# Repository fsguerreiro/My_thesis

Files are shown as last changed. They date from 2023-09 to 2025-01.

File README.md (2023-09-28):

# My PhD thesis: Building Integration of a Solar Air Heating System

### Abstract:

In order to achieve the global carbon emission target, the high fraction of locally
available renewable energy sources will become necessary to meet energy demand. Solar
energy is one of the most important renewable sources locally available for use in space
heating, cooling, hot water supply and power production. Building integrated solar thermal systems (BISTS) can be a potential solution towards the enhanced energy efficiency
and reduced operational cost in built environment. The current research aimed at developing an active solar air heating collector for building integration. This system consisted of
several asymmetric compound parabolic concentrating collectors with inverted transpired
absorber stacked on the top of each other capable of receiving direct solar insolation for 8
hours/day during the summer season. An optical analysis was carried out with the assistance of a 3D ray tracing technique in order to investigate the optical performance through
a parametric analysis, and thus to decide the design to be used as a prototype. It has dimensions of 0.42 m x 0.40 m x 1.25 m and concentration ration 2.28, able to absorb up
to 67% of direct solar radiation in the period of operation. Subsequently, the prototype
was experimentally tested by using five different air flow rates (22 – 60 kg/h) in open loop
configuration. Experimental results show that, on clear days and in periods of high solar
insolation (greater than 800 W/m²), the airflow temperature rise varied between 12 ºC
(at the highest airflow rate) and 27 ºC (at the smallest rate), characterising thus thermal
efficiencies between 52 – 62%. After experimental characterisation, a thermal modelling
based on energy balance was undertaken with the objective of simulating the collector’s
thermal performance for further control of multiple units connected altogether. Validation of this model indicates that it predicts data of air temperature delivered and energy
collected with uncertainties of ± 2 ºC and ± 50 W/m² of absorber area, respectively. The
thermal modelling was also used to predict the thermal performance of three collectors
connected in series and in parallel. The connection in series was able to deliver higher
outlet airflow temperatures (higher than 70 ºC on a clear day), whereas the connection in
parallel can collect more useful heat but delivering the same airflow temperature as if it
is leaving the first collector in series. Lastly, this model was used for simulating barley
drying. Three scenarios were employed to fulfill energy requirements: using only a gas
burner to heat the airflow to 60 °C, combining a solar heating system with a gas burner
to achieve the same temperature, and solely relying on the solar heating system without
an air temperature limit. For a specific airflow level, the gas burner system consumed the
most gas and had a solar fraction of 0, indicating full reliance on gas for heating. Conversely, the standalone Solar Air Heating System (SAHS) yielded less dried mass, but
both configurations achieved a solar fraction of 1, signifying exclusive reliance on solar
energy. Results demonstrate that incorporating solar air heating systems can significantly
reduce the need for natural gas heating. Specifically, the gas burner + SAHS in parallel
exhibited the lowest gas consumption and the highest solar fraction among all the gas
burner-based systems.

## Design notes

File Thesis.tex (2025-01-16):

\documentclass[12pt,a4paper,oneside,openright,fleqn]{report}

%----------------------------------- Loading packages==============================
\usepackage[a4paper,left=40mm,right=20mm,top=25mm,bottom=25mm,headheight=15pt,headsep=15pt,footskip=10mm,columnsep=1cm]{geometry}
\usepackage[backend=bibtex,style=authoryear,citestyle=authoryear,maxbibnames=8,maxcitenames=2,natbib=true,dashed=false,firstinits=true]{biblatex} %
\usepackage{latexsym,amssymb,amsmath,pifont} 				% Package of symbols
\usepackage[notintoc]{nomencl}										   % Insertion of List of Symbols
\usepackage{subcaption}                   								   % Captions in subfigures        
\usepackage{eurosym,wasysym}                                          % For the Euro symbol and other symbols
\usepackage[hidelinks,pdfencoding=auto]{hyperref}			 % Creation of hyperlink for citation
\usepackage{indentfirst} 		   		          							 % Indent first paragraph of a chapter
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
%\usepackage{rotating} 				              							% Rotation of figures
%\usepackage{fontenc}
%\usepackage{color} 						          						 % Edition of color in figures, pages, etc.
%\usepackage{yfonts}
%\usepackage{adjustbox}                                                   % Box an item (figure, text, etc.)
%\usepackage[bf]{caption} 												   % Edition of captions
%\usepackage{tablefootnote}												% Insertion of footnote in tables
%\usepackage{epstopdf}													  % Convert EPS to PDF file		
%\usepackage{url}
%\usepackage{fncychap} 
%\usepackage{lmodern} 
%\usepackage{bm}
%\usepackage{shorttoc} 
%\usepackage{lastpage} 
%\usepackage{changepage}
%\usepackage[normalem]{ulem} 

% ------------------------------------- Page settings =======================
\parindent 1cm          
\doublespacing	   	   
\captionsetup[table]{skip=0pt}
\setlength{\emergencystretch}{8pt}

% ---------------------------------- List settings =========================
\setlist{align=left,leftmargin=*,noitemsep,nosep,topsep=6pt}
\renewcommand{\labelitemi}{$\checked$}
\newcounter{descriptcount}
\renewcommand*\thedescriptcount{Step \arabic{descriptcount}:}

%------------------------------ Nomenclature settings =====================
\makenomenclature
\renewcommand{\nomname}{List of Symbols}
\renewcommand\nomgroup[1]{%
	\vspace{0.6cm}
	\item[\bfseries
	\ifstrequal{#1}{N}{\Large \hspace*{1.5cm} Latin}{%
		\ifstrequal{#1}{P}{\Large \hspace*{1.5cm} Greek}{%
			\ifstrequal{#1}{S}{\Large \hspace*{1.5cm} Subscripts}{%
				\ifstrequal{#1}{A}{\Large \hspace*{1.5cm} Acronyms}}}}]}
\setlength{\nomitemsep}{-8pt}
%\renewcommand*\nompreamble{\begin{multicols}{1}}
%\renewcommand*\nompostamble{\end{multicols}}
%\setlength{\columnsep}{0.8cm}

%-------------------------------------- List of references settings ====================
\addbibresource{References.bib}
\renewbibmacro{in:}{}
\DeclareNameAlias{sortname}{last-first}

%-----------------------------------Title and subtitle settings ======================
\setcounter{tocdepth}{3}
\setcounter{secnumdepth}{3}
\titleformat{\chapter}[display]{\normalfont\Huge\filcenter \bfseries}
{\vspace{-1.5cm} \titlerule[4pt] \vspace{3pt} \titlerule \vspace{1pc}%
	\Huge\MakeUppercase{\chaptertitlename} \thechapter}
{1pc}{\titlerule[2pt] \vspace{1pc} \Huge \MakeUppercase}
\titlespacing{\section}{0pc}{1pc}{1pc}
\titlespacing{\subsection}{0pc}{1pc}{0.75pc}
\titlespacing{\subsubsection}{0pc}{0.75pc}{0.5pc}

%------------------------------------------Tikz settings ==============================
\usetikzlibrary{shapes.arrows,shapes.geometric,positioning,arrows.meta,shapes,backgrounds,angles, quotes, decorations.pathreplacing,datavisualization}
\let\svtikzpicture\tikzpicture
\def\tikzpicture{\noindent\svtikzpicture}
\tikzset{
	ultra thin/.style= {line width=0.1pt}, very thin/.style=  {line width=0.2pt},
	thin/.style= {line width=0.4pt},% thin is the default
	semithick/.style=  {line width=0.6pt}, thick/.style=      {line width=0.8pt},
	very thick/.style= {line width=1.2pt}, ultra thick/.style={line width=1.6pt}
}
\tikzstyle{startstop} = [draw, rounded rectangle, minimum width=1.75cm, minimum height=1cm,text centered, draw=black,very thick]
\tikzstyle{input} = [trapezium, trapezium left angle=70, trapezium right angle=110, text width=7cm, minimum height=1cm, text centered, draw=black,very thick, node distance = 5.25cm]
\tikzstyle{decision} = [diamond, text width = 2.5cm, draw=black,very thick, text centered, node distance = 3.5cm, inner sep = 0pt]
\tikzstyle{block} = [rectangle, draw=black,very thick, text width = 2cm, text centered, text height = 0.5cm]
\tikzstyle{line} = [draw=black,very thick, -latex]
\tikzstyle{arrow} = [very thick,->,>=stealth]

\tdplotsetmaincoords{60}{110}
\pgfmathsetmacro{\rvec}{1.25}
\pgfmathsetmacro{\thetavec}{40}
\pgfmathsetmacro{\phivec}{40}

%------------------------------------------------ Initiating text ==========================

\begin{document}
	\raggedbottom
	\sloppy
	\setlength{\belowdisplayskip}{10pt}      \setlength{\abovedisplayskip}{-4pt}
	\pagenumbering{gobble}
	\input{Cover}
	
	\newpage
	\thispagestyle{empty}
	\printnomenclature[1.5cm]
	\newpage
	
	%\setcounter{page}{1}       \pagenumbering{roman}
	\pagestyle{fancy}		\lhead{}		\rhead{\nouppercase{\rightmark}}
	
	\clearpage     						\renewcommand*\contentsname{Table of contents}
	\tableofcontents				 \addtocontents{toc}{~\hfill\textbf{Page}\par}
	
	\clearpage     \addcontentsline{toc}{chapter}{List of Figures} 	  \listoffigures
	
	\clearpage     \addcontentsline{toc}{chapter}{List of Tables}      \listoftables
	
	\newpage
	\rhead{\nouppercase{\rightmark}}      \lhead{Chapter \thechapter}
	\setcounter{page}{1}       \pagenumbering{arabic}
	\input{Introduction}
	\input{Literature}
	\input{Optical}
	\input{Experimental}
	\input{Thermal}

	\input{Conclusions}
	\newpage
	\lhead{}
	\addcontentsline{toc}{chapter}{References}
	\printbibliography[title={References}]
	%\newpage
	
\end{document}

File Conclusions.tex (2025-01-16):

\chapter{Conclusions}
\label{Cap:Con}
%

%The conclusions from this PhD work are listed as follows:
%
%\begin{itemize}
%	\item Development of a 3D ray tracing for optical analysis of direct radiation to assist the selection of a collector design: an optical analysis has been undertaken to evaluate its optical efficiency considering factors as: glazing transmittance, truncation level, length and tertiary section height. The results show that there is a maximum value of optical efficiency for a particular parabolic reflector shape and a maximum value of glazing transmittance at different inclinations. The proposed air heater concentrator is able to absorb in average 67\% of direct solar radiation during most part of the day in the period evaluated;
%	
%	\item Performance of experimental work to characterise the specific type of collector:
%	the experiments were carried out in open loop configuration, where the air was blown by a 12-W fan with a voltage adaptor to vary the airflow rate. Experimental results were analysed for different airflow rates ranging between 0.04 and 0.115 kg/m$^2$.s. Results show that the maximum outlet air temperatures at solar noon (13:00 to 14:00) varied from 40 $^{\rm{o}}$C at the highest airflow to 52 $^{\rm{o}}$C at the lowest and the thermal efficiency varied from 52\% to 62\%. 
%	
%	\item Thermal modelling of the solar air heating concentrator and validation against experimental results: it was shown that, in general, the heat transfer model underestimates 65\% of the data and 95\% of the residues generated are between $\pm$2 $^{\rm{o}}$C and $\pm$50 W/m$^2$. In overall, the mean absolute error in terms of temperature was found to be 2\% and in terms of useful energy was 8\%. The model was also used to simulate results at nearly steady state condition. The thermal efficiency curve was plotted and compare it to the experimental one. The parameters of the Hottel-Whillier-Bliss equation were calculated by the thermal model with relative difference of 2\% and 10\%, respectively, in relation to the parameters of the experimental data.
%	
%	\item Thermal simulation of a system consisted of more than one collector connected together: The thermal modelling was also used to predict the thermal performance of three connected collectors in series and in parallel. The connection in series is able to deliver higher outlet airflow temperatures whereas the connection in parallel can collect more useful heat but delivering the same airflow temperature as if it is leaving the first collector in series.
%	
%	
%	\item Use of this thermal model for simulating barley drying: Three scenarios were considered to meet the energy demand: simulating only a gas burner to heat the airflow up to 60 $^{\rm{o}}$C; simulating the solar heating system and a gas burner to heat the airflow up to 60 $^{\rm{o}}$C, and; simulating only the solar heating system to heat the airflow with no air temperature limit. From an specific airflow level used in the simulations, the gas burner system has the highest gas volume consumption and a solar fraction of 0, meaning it relies completely on gas for heating. On the other hand, the SAHS standalone system produces less dried mass, but both connections have a solar fraction of 1, indicating that they rely solely on solar energy.
%	
%	
%\end{itemize}

%\begin{itemize}
%	\item Development of a 3D ray tracing method for optical analysis of direct radiation to assist in the selection of a collector design: An optical analysis was conducted to evaluate its optical efficiency, considering factors such as glazing transmittance, truncation level, length, and tertiary section height. The results indicate a maximum optical efficiency for a specific parabolic reflector shape and a peak glazing transmittance at different inclinations. The proposed air heater concentrator demonstrated the ability to absorb an average of 67\% of direct solar radiation during the evaluated period of the day.
%	
%	\item Performance of experimental work to characterise the specific type of collector: Experiments were carried out in an open-loop configuration, where air was blown using a 12-W fan with a voltage adaptor to vary the airflow rate. Experimental results were analysed for different airflow rates ranging from 0.04 to 0.115 kg/m$^2\cdot$s. The findings reveal that the maximum outlet air temperatures at solar noon (13:00 to 14:00) varied from 40\,$^{\circ}$C at the highest airflow to 52\,$^{\circ}$C at the lowest, with thermal efficiencies ranging between 52\% and 62\%.
%	
%	\item Thermal modelling of the solar air heating concentrator and validation against experimental results: The heat transfer model was found to underestimate 65\% of the data, with 95\% of the residuals falling within \(\pm2\,^{\circ}\text{C}\) and \(\pm50\,\text{W/m}^2\). Overall, the mean absolute error in temperature was 2\%, and in useful energy, it was 8\%. The model was also used to simulate results under nearly steady-state conditions. The thermal efficiency curve was plotted and compared with experimental data. The parameters of the Hottel-Whillier-Bliss equation were calculated by the thermal model, showing relative differences of 2\% and 10\%, respectively, compared to the experimental parameters.
%	
%	\item Thermal simulation of a system comprising multiple collectors connected together: The thermal model was employed to predict the thermal performance of three collectors connected in series and in parallel. The series connection was found to deliver higher outlet airflow temperatures, while the parallel connection captured more useful heat but delivered airflow temperatures equivalent to those from the first collector in the series.
%	
%	\item Application of the thermal model for simulating barley drying: Three scenarios were analysed to meet the energy demand: (1) simulating only a gas burner to heat airflow to 60\,$^{\circ}$C; (2) simulating the solar heating system combined with a gas burner to achieve the same temperature; and (3) simulating the solar heating system alone, without a temperature limit. At a specific airflow level, the gas burner system exhibited the highest gas consumption and a solar fraction of 0, relying entirely on gas for heating. Conversely, the standalone solar air heating system produced less dried mass, but both configurations had a solar fraction of 1, indicating complete reliance on solar energy.

% \end{itemize}

%This chapter has consolidated the findings and highlighted key milestones achieved during the study of the proposed solar air heater concentrator and its applications.
%
%The design of an air heater concentrator with a horizontally downward-facing absorber proved effective in concentrating solar thermal energy and minimising heat losses. Through 3D ray-tracing optical analysis, the study identified an optimal parabolic reflector shape and glazing transmittance for different inclinations. A tertiary section was found to enhance uniformity in energy distribution across the absorber, although it introduced higher optical losses. Further exploration of the tertiary section's impact through thermal modelling and outdoor experiments remains necessary. The developed concentrator demonstrated an average absorption of 67\% of direct solar radiation during the evaluation period, showcasing its potential efficiency.
%
%The fabrication of a solar air heating prototype was successfully detailed, with materials selected based on their suitability for solar energy applications. The carbon fibre weave with 85\% absorptivity was chosen as the absorber, while the \textit{Mirosun} reflector sheet with 95\% reflectivity and tempered clear glass with 90\% transmittance served as the reflector and glazing, respectively. The experimental setup included a 12-W fan for airflow adjustment, enabling tests at varying flow rates. Results indicated that outlet air temperatures ranged from 40$^{\circ}$C  at the highest airflow to 52$^{\circ}$C  at the lowest, while thermal efficiency varied between 52\% and 62\% under peak solar noon conditions.
%
%Experimental findings were complemented by thermal modelling and simulation. Validation of the thermal model against experimental data showed a mean absolute error of 2\% for temperature and 8\% for useful energy. The parameters of the Hottel-Whillier-Bliss equation derived from the experimental data ( and ) closely matched those obtained from the model, with relative differences of 2\% and 10\%, respectively. The model’s robustness enabled simulations to predict performance under steady-state conditions and explore configurations of connected collectors. Collectors in series provided higher outlet air temperatures, whereas parallel connections increased useful heat collection without raising airflow temperatures beyond the initial collector’s output.
%
%The system’s potential for practical applications, such as barley drying, was investigated using the thermal model. Three scenarios highlighted the role of solar air heating systems (SAHS) in reducing dependence on natural gas. The standalone SAHS demonstrated a solar fraction of 1, while the gas burner + SAHS parallel configuration achieved the lowest gas consumption and highest solar fraction among hybrid systems. These findings underscore the potential for significant reductions in natural gas reliance, contingent on sunlight availability, natural gas costs, and system accessibility.
%
%In summary, this study has successfully designed, fabricated, and evaluated a solar air heating system. Key milestones include identifying optimal design parameters, validating a thermal model against experimental data, and demonstrating the system’s practical applications. The results reinforce the viability of solar air heating as a sustainable and efficient alternative to conventional energy sources, with opportunities for further optimisation and scalability.

This chapter concludes the research undertaken for this PhD by summarising its key findings, revisiting the objectives and contributions, and outlining potential directions for future work. The study focused on the development, testing, and modelling of a solar air-heating concentrator, aiming to enhance its design and performance for building-integrated applications. In the final phase, the system’s modelling was applied to address the energy demands of a barley drying operation. 

The chapter is organized as follows:

\begin{itemize}
	\item A detailed summary of the primary conclusions of this research and key findings, addressing the specific objectives described in Chapter \ref{Cap:Int};
	\item Suggestions for future research to build upon the outcomes.
\end{itemize}

\section{Main conclusions and key findings}

The main conclusions drawn from this PhD research are summarised as follows:

\begin{itemize}
	\item \textbf{Development of a 3D ray-tracing model for optical analysis of direct radiation to assist in the selection of a collector design}: \\
	A comprehensive optical analysis was conducted to evaluate the optical efficiency of the proposed collector design, considering factors such as glazing transmittance, truncation level, length, and tertiary section height. The findings reveal that there was an optimal parabolic reflector shape that maximises optical efficiency, as well as a peak glazing transmittance value for specific inclinations. The analysis was also able to calculate the effect of the tertiary section height on the energy distribution over the absorber plate. All of those design parameters were evaluated to select the concentrator's shape and size for further fabrication: concentration ratio of 2.28 and capability to absorb, on average, 67\% of direct solar radiation during the evaluated period for most of the day;
	
	\item \textbf{Performance of experimental work to characterise the specific type of collector}: \\
	Experiments were conducted in an open-loop configuration, where air was blown by a 12-W fan with a voltage adaptor used to vary the airflow rate. The experimental data were obtained for airflow rates ranging from 0.04 to 0.115 kg/(m$^2\cdot$s). The results indicate that the maximum outlet air temperatures at solar noon (13:00 to 14:00) ranged from 40 $^{\circ}$C at the highest airflow rate to 52 $^{\circ}$C at the lowest. The thermal efficiency varied between 52\% and 62\%, depending on the airflow rate;
	
	\item \textbf{Thermal modelling of the solar air heating concentrator and validation against experimental results}: \\
	A heat transfer model was developed and validated against experimental data. Although the model underestimated 65\% of the experimental values, 95\% of the residuals were within $\pm$2~$^{\circ}$C for temperature and $\pm$50~W/m$^2$ for useful energy. The mean absolute error was determined to be 2\% for temperature and 8\% for useful energy. Additionally, the model was employed to simulate steady-state conditions, with the resulting thermal efficiency curve compared to experimental data. The parameters of the Hottel-Whillier-Bliss equation were derived from the thermal model, yielding relative differences of 2\% and 10\%, respectively, when compared to the experimentally obtained parameters.
	
	\item \textbf{Thermal simulation of a system comprising multiple collectors connected together}: \\
	The thermal model was extended to predict the performance of systems with three collectors connected in series and parallel configurations. The series configuration yielded higher outlet air temperatures, while the parallel configuration collected more useful heat but delivered airflow temperatures equivalent to those exiting the first collector in the series setup;
	\\
	
	\item \textbf{Application of the thermal model for simulating barley drying}: \\
	Three scenarios were evaluated to meet the energy demand for barley drying: 
	\begin{enumerate}
		\item Simulating a gas burner to heat the airflow up to 60~$^{\circ}$C.
		\item Simulating a hybrid system with a solar heating system and a gas burner to heat the airflow up to 60~$^{\circ}$C.
		\item Simulating the solar heating system alone, with no upper temperature limit for the airflow.
	\end{enumerate}
	The simulations revealed that the gas burner system had the highest gas consumption, with a solar fraction of 0, indicating total reliance on gas for heating. Conversely, the standalone solar air heating system (SAHS) produced less dried mass but achieved a solar fraction of 1 in both series and parallel configurations, demonstrating complete reliance on solar energy. Additionally, the results indicate that the combination of gas burner + SAHS in parallel configuration exhibited the lowest gas consumption and highest solar fraction among all the listed systems with gas burner.
	
\end{itemize}

%The suggestions for the future are listed as follows:
%
%\begin{itemize}
%	\item Use the ray tracing technique to simulate diffuse radiation in 3D to have better results for optical modelling;
%    \item Run experiments using more than one solar air heating collector connected to find the best configuration in terms of air temperature delivered and energy collection.
%    \item Perform a Computational Fluid Dynamics (CFD) modelling to better understand the heat transfer within the concentrator. Simulations will be undertaken to investigate the effect of the tertiary section height and the collector's size;
%    \item Develop a control algorithm to deliver airflow temperature at a certain set-point and further use of proper equipment to maintain this air temperature at the set-point according to the application required.
%    \item Couple a solar air heating system to a real dryer and run experiments to measure how much barley can be dried at a fixed air temperature.
%\end{itemize}

\section{Suggestions for future work}

From the findings of this research, several areas are identified for further exploration:

\begin{itemize}
	\item \textbf{Use of the ray tracing technique to simulate diffuse radiation in 3D for improved optical modelling}: \\
	Extending the ray tracing methodology to include simulations of diffuse radiation will enhance the accuracy of optical modelling. This improvement is expected to provide a more comprehensive understanding of the concentrator's performance under realistic solar radiation conditions.
	
	\item \textbf{Conducting experiments with multiple solar air heating collectors connected together}: \\
	Experimental studies should investigate the performance of systems comprising multiple collectors connected in series and parallel configurations. These experiments will aim to identify the optimal configuration in terms of delivered air temperature and overall energy collection efficiency.
	
	\item \textbf{Performing Computational Fluid Dynamics (CFD) modelling to analyse heat transfer within the concentrator}: \\
	Advanced CFD simulations should be undertaken to gain deeper insights into the heat transfer mechanisms within the concentrator. These simulations can explore the effects of design parameters such as the tertiary section height and collector size on thermal performance, thereby informing future design improvements.
	
	\item \textbf{Developing a control algorithm for maintaining a set-point airflow temperature}: \\
	A control algorithm should be devised to regulate the airflow temperature at a desired set-point, tailored to the specific application. Additionally, appropriate equipment, such as thermostats or variable-speed fans, should be integrated to ensure that the system maintains the set-point temperature efficiently under varying operating conditions.
	
	\item \textbf{Coupling the solar air heating system with a real dryer for experimental evaluation}: \\
	A solar air heating system should be coupled with a functional drying system to perform experiments on real-world applications, such as barley drying. These experiments should aim to quantify the amount of barley that can be dried at a controlled air temperature, providing valuable data for assessing the system's feasibility and efficiency in agricultural or industrial settings.
\end{itemize}

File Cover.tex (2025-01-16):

%\thispagestyle{empty}
\begin{center}
	\Figure[scale=0.35,placement=!ht,label={logoDIT}]{figs/TUD-logo}
	{\LARGE {\bf Building Integration of a Solar Air \\ Heating System}} \\
	\vspace{2cm}
	{\Large {\bf Fernando Superbi Guerreiro, BSc, MSc}} \\
	\vspace*{1cm}

	{\large A thesis submitted in fulfilment of the requirements for the degree of Doctor of Philosophy}
	
	\vspace*{1cm}
	
	{\large Under the supervision of \\ Dr. Michael McKeever, Prof. David Kennedy,
	    Prof. Brian Norton}
    
    \vspace*{1cm}
    
	{\large	School of Electrical and Electronic Engineering \\
		Technological University Dublin \\
		Republic of Ireland \\
		November 2024 \\}
	
\end{center}

\newpage
\setcounter{page}{1}       \pagenumbering{roman}
\chapter*{Abstract}
%\thispagestyle{empty}
\vspace*{1cm}

In order to achieve the global carbon emission target, the high fraction of locally available renewable energy sources will become necessary to meet energy demand. Solar energy is one of the most important renewable sources locally available for use in space heating, cooling, hot water supply and power production. Building integrated solar thermal systems (BISTS) can be a potential solution towards the enhanced energy efficiency and reduced operational cost in built environment. The current research aimed at developing an active solar air heating collector for building integration. This system consisted of several asymmetric compound parabolic concentrating collectors with inverted transpired absorber stacked on the top of each other capable of receiving direct solar insolation for 8~hours/day during the summer season. An optical analysis was carried out with the assistance of a 3D ray tracing technique in order to investigate the optical performance through a parametric analysis, and thus to decide the design to be used as a prototype. It has dimensions of 0.42 m x 0.40 m x 1.25 m and concentration ration 2.28, able to absorb up to 67\% of direct solar radiation in the period of operation. Subsequently, the prototype was experimentally tested by using five different air flow rates (22 -- 60 kg/h) in open loop configuration. Experimental results show that, on clear days and in periods of high solar insolation (greater than 800 W/m$^{\rm{2}}$), the airflow temperature rise varied between 12 $\rm{^oC}$ (at the highest airflow rate) and 27 $\rm{^oC}$ (at the smallest rate), characterising thus thermal efficiencies between 52 -- 62\%. After experimental characterisation, a thermal modelling based on energy balance was undertaken with the objective of simulating the collector’s thermal performance for further control of multiple units connected altogether. Validation of this model indicates that it predicts data of air temperature delivered and energy collected with uncertainties of $\pm$ 2 $\rm{^oC}$ and $\pm$ 50 W/m$^{\rm{^2}}$ of absorber area, respectively. The thermal modelling was also used to predict the thermal performance of three collectors connected in series and in parallel. The connection in series was able to deliver higher outlet airflow temperatures (higher than 70 $\rm{^oC}$ on a clear day), whereas the connection in parallel can collect more useful heat but delivering the same airflow temperature as if it is leaving the first collector in series. Lastly, this model was used for simulating barley drying. Three scenarios were employed to fulfill energy requirements: using only a gas burner to heat the airflow to 60°C, combining a solar heating system with a gas burner to achieve the same temperature, and solely relying on the solar heating system without an air temperature limit. For a specific airflow level, the gas burner system consumed the most gas and had a solar fraction of 0, indicating full reliance on gas for heating. Conversely, the standalone Solar Air Heating System (SAHS) yielded less dried mass, but both configurations achieved a solar fraction of 1, signifying exclusive reliance on solar energy. Results demonstrate that incorporating solar air heating systems can significantly reduce the need for natural gas heating. Specifically, the gas burner + SAHS in parallel exhibited the lowest gas consumption and the highest solar fraction among all the gas burner-based systems.

%\newpage
%\relax
\chapter*{Declaration}
%\thispagestyle{empty}
\vspace*{1cm}

\noindent I certify that this thesis which I now submit for examination for the award of PhD, is entirely my own work and has not been taken from the work of others, save and to the extent that such work has been cited and acknowledged within the text of my work.
\\ \\
\noindent This thesis was prepared according to the regulations for graduate study by research of the Technological University Dublin and has not been submitted in whole or in part for another award in any other third level institution.
\\ \\
\noindent The work reported on in this thesis conforms to the principles and requirements of the TU Dublin's guidelines for ethics in research.
\\ \\
\noindent TU Dublin has permission to keep, lend or copy this thesis in whole or in part, on condition that any such use of the material of the thesis be duly acknowledged. 

\vspace*{3cm}

\noindent \parbox[t]{2cm}{Signature Candidate} \makebox[6cm]{\hrulefill} \hfill Date \makebox[3cm]{\hrulefill} \\
%\noindent Candidate
%Candidate

%\newpage
\chapter*{Acknowledgement}
%\thispagestyle{empty}
\vspace*{1cm}

I would like to express my sincere appreciation to the individuals and organizations who have provided support and guidance throughout my PhD journey. I am deeply grateful to my supervisors, Professor Mick McKeever, Professor David Kennedy, and Professor Brian Norton, for their unwavering encouragement, support, and valuable insights.

In addition, I would like to thank my thesis committee members for their constructive criticism and feedback, which significantly improved the quality of my research.

I am thankful for the welcoming and supportive research environment created by the staff and students of TU Dublin. Working with inspiring and talented individuals has been a privilege, and I am grateful for the collaborations and friendships that have emerged from this community.

My family has been a constant source of love, support, and encouragement throughout my academic journey, and I am deeply indebted to them for their sacrifices and unwavering belief in my abilities.

I would also like to acknowledge the invaluable support and encouragement of my friends, who have provided inspiration and motivation during the ups and downs of my research journey.

Finally, I would like to acknowledge the National Council for Scientific and Technological Development (CNPq: process number 233789/2014-6) for providing me financial support to complete this PhD.

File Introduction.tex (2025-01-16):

\chapter{Introduction}
\label{Cap:Int}

%To achieve the carbon emission target, high fraction of locally available renewable energy sources will become necessary to reduce energy demand. Solar energy is one of the most important renewable sources for use in building heating, cooling, hot water supply and power production. Solar thermal systems for water and air heating are well established technologies. Their use promotes environmental sustainability, as it eliminates the need to provide heat by combusting of fossil fuels therefore contributing to reducing greenhouse gases emissions. Building integrated solar thermal systems (BISTS) can be a potential solution towards the enhanced energy efficiency and reduced operational cost in contemporary built environment. According to the vision plan issued by European Solar Thermal Technology Platform (ESTTP), by 2030 up to 50\% of the low and medium temperature heat will be delivered through solar thermal systems (\cite{ESTTP2009}).

To achieve the carbon emission target, a high fraction of locally available renewable
energy sources will become necessary to reduce energy demand. Solar energy is one of
the most important renewable sources for building heating, cooling, hot water
supply, and power production. Solar thermal systems for water and air heating are
well-established technologies. Their use promotes environmental sustainability, eliminating the need to provide heat by combusting fossil fuels, thereby reducing greenhouse gas emissions. Building integrated solar thermal systems (BISTS)
can be a potential solution towards enhanced energy efficiency and reduced operational
costs in the contemporary built environment. According to the vision plan issued by the
European Solar Thermal Technology Platform (ESTTP), by 2030, up to 50\% of low and
medium-temperature heat will be delivered through solar thermal systems (\cite{ESTTP2009}).

%To achieve the carbon emission target, a high fraction of locally available renewable energy sources will become necessary to reduce energy demand. Solar energy is one of the most important renewable sources for use in building heating, cooling, hot water supply, and power production. Solar thermal systems for water and air heating are well-established technologies. Their use promotes environmental sustainability, as they eliminate the need to provide heat by combusting fossil fuels, thereby contributing to the reduction of greenhouse gas emissions. Building integrated solar thermal systems (BISTS) can be a potential solution towards enhanced energy efficiency and reduced operational costs in the contemporary built environment. According to the vision plan issued by the European Solar Thermal Technology Platform (ESTTP), by 2030, up to 50\% of low and medium-temperature heat will be delivered through solar thermal systems (\cite{ESTTP2009}).

%Solar air heating collectors transfer solar thermal energy from an absorbing surface to an airflow. The heated air can be used for applications, such as space heating, timber seasoning, curing of industrial products and food drying (\cite{Shams2016}), as can be seen in Table \ref{air-application} with the corresponding air temperature range. A solar air heater can integrate to a concentrator to produce air at medium or high temperatures (\cite{Duffie2013}). A concentrating collector combining inverted absorber and asymmetric compound parabolic concentrator (IACPC), in which solar radiation is reflected to be incident from below onto the absorbing surface, has been proposed by \citet{Rabl1976}. Although there are optical losses due to the multiple reflections of incident solar energy (\cite{Kothdiwala1996}), this type of concentrator is able to achieve higher absorber temperatures by suppressing convective and radiative heat losses (\cite{Kothdiwala1999}). A competing technology for this application is on evacuated tube collectors (ETC). This also has optical losses due to reflection from the tubular aperture. An ETC's low heat losses arise from a vacuum between the glass tube envelope and an absorber. As well as limiting long-term durability, this is challenging to fabricate and to envelope the large cross-section duct required for airflow. 

Solar air heating collectors transfer solar thermal energy from an absorbing surface to an airflow. The heated air can be used for applications such as space heating, timber seasoning, curing industrial products, and food drying (\cite{Shams2016}), as shown in Table \ref{air-application} with the corresponding air temperature ranges. A solar air heater can integrate with a concentrator to produce air at medium or high temperatures (\cite{Duffie2013}). A concentrating collector combining an inverted absorber and asymmetric compound parabolic concentrator (IACPC), in which solar radiation is reflected to be incident from below onto the absorbing surface, was proposed by \citet{Rabl1976}. Although there are optical losses due to the multiple reflections of incident solar energy (\cite{Kothdiwala1996}), this type of concentrator can achieve higher absorber temperatures by suppressing convective and radiative heat losses (\cite{Kothdiwala1999}). A competing technology for this application is evacuated tube collectors (ETC). These also have optical losses due to reflection from the tubular aperture. An ETC’s low heat losses arise from a vacuum between the glass tube envelope and the absorber. However, the design limits long-term durability and poses challenges for fabricating and enclosing the large cross-section duct required for airflow.

\begin{table}[!ht]
	\caption{Application for air heating and operating air temperature range. From \citet{Norton2012} and \citet{Pranesh2019}}
	\centering
	\begin{tabular}{p{4cm}p{4cm}}
		\hline \\[-10pt]
		Application & Temperature range ($^{\rm{o}}$C) \\
		\hline \\[-10pt]
		Timber drying & 60 -- 100 \\ [3pt]
		Food drying & 30 -- 90 \\ [3pt]
		Brick curing & 60 -- 140 \\ [3pt]
		Space heating & 30 -- 100 \\ [3pt]
		\hline
	\end{tabular}
\label{air-application}
\end{table}

An IACPC was designed to be used as a solar air heater collector by \citet{Shams2013}. This collector had a perforated absorber surface made of carbon fibre placed at a fixed cavity height, a glazed aperture, a concentration ratio of 2.0, and was optically characterised and experimentally tested at different airflow rates. In this design, the air inlet was located at one end below the absorber, and the outlet was placed at the top near the other end. The lowest experimental airflow rate (0.03~kg/(m\textsuperscript{2}·s)) resulted in the highest temperature rise of 38 \textdegree C at a radiation level of 1000~W/m\textsuperscript{2}. The highest experimental operating flow rate (0.09~kg/(m\textsuperscript{2}·s)) resulted in a temperature rise of 19.6 \textdegree C at a radiation level of 1000~W/m\textsuperscript{2}.

%An IACPC was designed to be used as a solar air heater collector by \citet{Shams2013}. This collector had a perforated absorber surface made of carbon fibre placed at a fixed cavity height, a glazed aperture, a concentration ratio of 2.0, and was optically characterised and experimentally tested at different airflow rates. In this design, the air inlet was located at one end below the absorber and the outlet was placed at the top near the other end. The lowest experimental airflow rate (0.03 kg/(m$^2$.s)) resulted in the highest temperature rise of 38 $^{\rm{o}}$C at a radiation level of 1000 W/m$^2$. The highest experimental operating flow rate (0.09 kg/(m$^2$.s)) resulted in a temperature rise of 19.6 $^{\rm{o}}$C at a radiation level of 1000 W/m$^2$.

%This current research designed IACPC collectors to be stacked on a wall. The collector had a vertical aperture so that shading could be avoided when two or more collectors are stacked on a vertical wall, enabling the full façade area available to be harnessed (as shown in Figure \ref{array1}). The concentration ratio was increased to receive more solar radiation. However, solar air heating systems comprising more than one interconnected IACPC collector have not been thermal characterised to date. The number of collectors needed to meet air temperature requirement for specified conditions is not known nor is the cost involved. The behaviour of the airflow and the heat transfer mechanism inside the collector have never been studied in sufficient detail to enable detailed parametric analysis. Such understanding will allow designers to propose improvements to the system. Based on the scale and size of the collector developed, the system has the potential application for pre-heating fresh air for buildings.

This current research designed IACPC collectors to be stacked on a wall. The collector has a vertical aperture so that shading can be avoided when two or more collectors are stacked on a vertical wall, enabling the entire façade area to be harnessed (as shown in Figure \ref{array1}). The concentration ratio was increased to receive more solar radiation. However, solar air heating systems comprising more than one interconnected IACPC collector have not yet been thermally characterised. The number of collectors needed to meet air temperature requirements for specified conditions is unknown, nor is the cost involved. The behaviour of the airflow and the heat transfer mechanism inside the collector have never been studied in sufficient detail to enable detailed parametric analysis. Such understanding will allow designers to propose improvements to the system. Based on the scale and size of the collector developed, the system has potential applications for pre-heating fresh air for buildings and agricultural purposes.

\Figure[scale=0.40,placement=!ht,label={array1},caption={Array of 3 collectors stacked on a 1-m$^2$ fa\c{c}ade wall.}]{figs/array1.png}

\section{Aim and objectives of this research}
This research aims to design a solar air heating system (SAHS) comprising  an asymmetric compound parabolic concentrator with an inverted transpired absorber. The intended application constraint is a building integrated system consisting of multiple collectors capable of collecting solar radiation for eight hours per day during summer, delivering heated airflow. An array of three collectors, as depicted in Figure \ref{array1}, exemplifies a system configuration. The specific objectives are to:

\begin{itemize}
	\item create a robust mathematical model capable of accurately designing the collector's shape, ensuring that the geometry aligns with the desired operational and application constraints;
	\item use the developed model for evaluating the optical performance of the collector using a 3D ray tracing technique. This assessment will help identify and optimise the collector’s design parameters, including its ability to collect and concentrate solar radiation efficiently;
	\item fabricate a prototype of the solar collector and conduct field tests. These tests aim to characterise the collector and gain a thorough understanding of the key operational variables affecting its performance under real-world conditions;
	\item simulate the transient thermal behaviour of the collector through heat transfer modelling. The simulation results will be validated against experimental data obtained from the prototype, ensuring the model’s accuracy and reliability;
	\item extend the validated thermal model for simulating the performance of systems with multiple collectors connected in series and parallel. This simulation will provide insights into how such configurations can achieve higher airflow temperatures or increase the total energy output;
	\item apply the validated thermal model to simulate the system’s performance in a practical agricultural context -- specifically, a barley drying process. The simulation will determine how effectively the SAHS can meet the energy demands of this application.

\end{itemize}

\section{Significant new knowledge to the research area}

%The significant new contribution to knowledge in the research area of solar thermal energy for air heating are:
%
%\begin{itemize}
%	\item development of an accurate model capable of bulding the shape of CPCs, ACPCs and coupled with inverted absorbers. It considers design parameters, such as parabolic shape, concentration ratio, truncation, length, inclination and absorber position;
%	\item coupling of this model to a 3D ray tracing technique that simulates direct solar radiation using solar angles (azimuth and altitude) from the Sun's position;
%	\item additional results obtained from an optical modelling in 3D when compared to the modelling in 2D, such as end losses and energy distribution along the absorber area;
%	\item thermal modelling and simulation of more than one collector connected in series and in parallel to deliver higher airflow temperatures or more useful energy rate;
%	\item use of the thermal modelling to simulate barley drying application to find how much energy can be replaced by the solar air heating system.
%\end{itemize}

The significant new contributions to knowledge in the field of solar thermal energy for air heating are detailed as follows:

\begin{itemize}
	\item \textbf{Advanced Modelling for Concentrator Design}:	development of an accurate computational model to design CPCs, ACPCs and inverted absorber configurations. It considers key design parameters such as reflectors' shape, concentration ratio, truncation, length, glazing inclination, and absorber positioning, enabling adaptability and performance optimisation across applications;
	
	\item \textbf{Integration with 3D Ray Tracing Technique}: integration of the model with a 3D ray tracing technique capable of accurately simulating direct solar radiation. This integration accounts for the Sun’s position using solar angles, including azimuth and altitude, to predict how sunlight enters the collector. Such simulations provide valuable insights into the optical efficiency of the concentrator system, enabling the optimisation of designs for enhanced energy collection;
	
	\item \textbf{Enhanced Insights from 3D Optical Modelling}: by employing 3D optical modelling, the research has uncovered additional phenomena not captured by traditional 2D modelling. These include detailed end-loss effects and a comprehensive understanding of energy distribution across the absorber surface. Such insights enable accurate system performance predictions and inform design improvements that minimise energy losses;
	
	\item \textbf{Thermal Modelling of Complex Collector Configurations}: development of a thermal model to simulate systems comprising multiple collectors arranged in series and parallel configurations. These setups provide enhanced versatility in addressing a variety of heating needs, such as reaching elevated airflow temperatures or boosting the overall useful energy collection. These innovations make the systems more suitable for use in industrial and agricultural sectors;
	
	\item \textbf{Application to Agricultural Drying Systems}: application of the thermal modelling to a practical case study involving barley drying, demonstrating the potential of solar air heating systems to replace conventional energy sources. The simulations quantify the energy savings achievable through this technology, highlighting its economic and environmental benefits. This application highlights the effectiveness of solar air heating systems as a sustainable option for agricultural processes.
\end{itemize}

The collective contributions enhance the understanding of solar thermal energy systems, establishing a basis for ongoing research and innovation. The findings offer practical solutions to improve energy efficiency and promotes the implementation of renewable energy technologies across different sectors.

\section{Thesis overview}

%\Figure[scale=0.47,placement=!ht,label={schematics_intro},caption={Research Methodology.}]{figs/schematics_intro.eps}

The research methodology is shown in Figure \ref{scheme-intro}, which provides the key topics of the systematic steps undertaken throughout the research process. The Thesis' chapters are depicted as follows:

\newpage

\begin{figure}[!ht]
	\centering
	\begin{tikzpicture}[scale=1, node distance = 5 cm, very thick]
		\node[block, text width=6cm] (intro) {Introduction and literature review};
		\node[block, below of=intro,text width=3cm,yshift=3cm] (mat) {Materials selection};
		\node[block, below of=mat,text width=3cm,yshift=2cm] (fab) {Fabrication of a prototype};
		\node[block, below of=fab,text width=3cm,yshift=2cm] (exp) {Thermal performance of the prototype};
		\node[block, left of=mat,text width=3cm] (opt) {Optical analysis};
		\node[block, left of=fab,text width=3cm] (opt2) {Optical characterisation and design};
		\node[block, right of=mat,text width=3cm] (thermal) {Thermal modelling};
		\node[block, right of=fab,text width=3cm] (thermal2) {Thermal simulation};
		\node[block, right of=exp,text width=3cm] (vali) {Modelling validation};
		\node[block, below of=exp,text width=5cm,yshift=2cm] (two) {Simulation of more than one prototype connected};
		\node[block, below of=two,text width=4cm,yshift=2.5cm] (dry) {Drying simulation};
		\draw[arrow] (intro) -- (mat);
		\draw[arrow] (mat) -- (fab);
		\draw[arrow] (fab) -- (exp);
		\draw[arrow] (exp) -- (two);
		\draw[arrow] (intro) -| (opt);
		\draw[arrow] (opt) -- (opt2);
		\draw[arrow] (opt2) -- (fab);
		\draw[arrow] (intro) -| (thermal);
		\draw[arrow] (thermal) -- (thermal2);
		\draw[arrow] (thermal2) -- (vali);
		\draw[arrow] (exp) -- (vali);
		\draw[arrow] (vali) |- (two);
		\draw[arrow] (two) -- (dry);
	\end{tikzpicture}
	%\label{scheme-intro}
	\caption{Research methodology.}
	\label{scheme-intro}
\end{figure}

\begin{itemize}
	\item Chapter \ref{Cap:Int} introduces the research topic, highlighting the motivation for the study and clearly defining the problem statement. It presents the research aim, outlines the specific objectives, emphasizes the contribution of new knowledge to the research area, and provides an overview of the methodology used to achieve these goals;
	\item Chapter \ref{Cap:Lit} -- Literature review: It comprehensively surveys the state-of-the-art in solar thermal collectors for medium-temperature applications, focusing on the key factors influencing thermal performance. It presents the optical characteristics of compound parabolic concentrators (CPCs) and explores methodologies for conducting optical analyses. Different designs for optical concentrators are assessed to discover other methods for focusing solar radiation onto an inverted absorber. In conclusion, the chapter presents a summary of building-integrated solar thermal collectors, emphasising their possible applications and advantages;
	\item Chapter \ref{Cap:Opt} -- Optical modelling and design analysis: presents the design of the solar air heating concentrator and the development of a model to calculate optical efficiency. It also depicts details of the concentrator's geometric specification. A 3D ray tracing technique implemented in Matlab software was developed to calculate the energy distribution at the absorber surface and the effect of the end plates on the optical performance;
	\item Chapter \ref{Cap:Exp} -- Experimental performance analysis: it describes the physical properties of the materials, fabrication and experimental characterisation of the built collector prototype at different airflow rates. The performance of the system depends on wind speed, solar radiation, inlet air and ambient temperatures;
	\item Chapter \ref{Cap:Thermal} -- Heat transfer modelling and simulation: depicts the heat transfer model developed to characterise and simulate the thermal performance of the proposed solar air heater in operation. This model was used to calculate the outlet airflow temperature and thermal efficiency, and experimental data was used to validate the model. Then, the model was used to simulate the thermal performance of collectors connected in series and parallel. Lastly, the validated model was used as an energy input for simulating barley drying to meet the energy demand for an application;
	\item Chapter \ref{Cap:Con} -- Conclusions: It concisely summarises each chapter and key findings, and offers thoughtful recommendations for future work to build on the study's outcomes.
\end{itemize}

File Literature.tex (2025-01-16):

\chapter{Literature Review}
\label{Cap:Lit}
%

This chapter depicts the concept and characteristics of solar air heating collectors -- unglazed and glazed collectors. Considerations were given to:

\begin{itemize}
	\item Elements and factors to affect collector's performance;
	\item Optical concentrator, specifically ACPC with inverted absorber;
	\item Building integration of solar thermal systems.
\end{itemize}

\section{Solar air heating collectors}

Solar air heating collectors (SAHCs) are equipment designed to receive solar radiation and convert it into heat for working air heating. They are widely applied in many commercial applications, such as hot air supply to shopping malls, agricultural barns, industrial drying, etc. They are usually low-cost, with no freezing and high-pressure problems. Compared to water-heating solar collectors, SAHCs are outperformed due to their air thermal properties (\cite{Buker2015}). To overcome this challenge, the heat transfer from the hot absorber surface of the collector to the air needs to be enhanced while the collector's overall heat losses are minimised. (\cite{Shams2013}).

SAHCs can be classified into two main types: unglazed and glazed. The fundamental difference between these types is the presence of a glazing cover and the shape of the absorber surface. Unglazed air heating collectors (also known as Unglazed Transpired Solar Collectors -- UTSCs) do not have any glazing cover; they are composed of a perforated (transpired) absorber plate, as shown in Figure \ref{unglazed-glazed}(a). The absorber plate can be integrated into building fa{\c c}ades. The contact between the absorber plate and ambient air is increased by drawing air through the multiple perforations into the cavity (also called plenum) between the plate and the fa{\c c}ade (\cite{Shukla2012}). A fan pulls this heated air in the plenum into the building (\cite{Buker2015}).

The other main type is the glazed SAHC (or Glazed Air Heating Collector -- GAHC), which has at least a flat glazing cover to prevent the absorber from being exposed to the ambient and avoid efficiency losses. A typical design can be seen in Figure \ref{unglazed-glazed}(b). The air is pulled into the collector by a fan to be heated after contact with the absorber plate, which can have different shapes and/or other modifications to enhance the transfer mechanism.

\Figure[scale=0.58,placement=!ht,label={unglazed-glazed},caption={Illustration of (a) an unglazed and (b) a glazed solar air heating collector. From \citet{Kutscher1994} and \citet{SolarTribune2011}.}]{figs/unglazed-glazed.png}    

To improve the heat transfer from the hot absorber surface to the working air, a wide range of designs for SAHCs has been studied and reported in the literature: glazed, unglazed, bare plate, back-pass, perforated, un-perforated, single, double or triple passes, etc. (\cite{Kutscher1994}; \cite{Christensen1997}; \cite{Gawlik2005}; \cite{Koyuncu2006}; \cite{Leon2007}; \cite{Tchinda2008}; \cite{El-Sebaii2010}; \cite{Athienitis2011}; \cite{Zheng2016}; \cite{Li2016}). %To understand how SAHCs' thermal efficiency is improved, it is worthy defining the response variables to quantify the performance, depicted as follows: 

\subsection{Energy analysis}

Defining the response variables is worth quantifying to understand how SAHCs' thermal performance is improved. The thermal efficiency is defined as the ratio of useful energy rate collected by the working fluid to the incoming total solar radiation $\rm{I_{\!_T}}$ (W/m$^{2}$) received on the aperture area $\rm{A_{apt}}$ (m$^{2}$), calculated by Eq. (\ref{ThermalEf0}). Such efficiency can be evaluated either instantaneously or as an average over a certain period (\cite{Goswami2015}):

\begin{equation}
	\mathrm{\mathlarger{\eta}_{\mathrm{th}} = \frac{Q_u}{I_{\!_T}A_{apt}}}
	\label{ThermalEf0}
\end{equation}

\noindent where the useful energy rate $\rm{Q_u}$ (W) can be calculated considering the airflow rate $\rm{m_{air}}$ (kg/s), the temperature difference between outlet and inlet (\textdegree C), and the specific heat of the air (J/(kg.\textdegree C)) at constant pressure:

\begin{equation}
	\mathrm{{Q_u} = {m_{air}}{C_{p,air}}({T_{out}} - {T_{in}})}
	\label{usefulenergy0}
\end{equation}

The thermal characterisation of an SAHC relates the thermal efficiency under steady-state conditions to each temperature rise normalised by the corresponding solar radiation according to the Hottel-Whillier-Bliss equation, expressed by Eq. (\ref{hottel-whiller-eq0}).

\begin{equation}
	\mathrm{\eta_{\rm{th}} = \eta_o - {U_{\!_L}}\frac{(T_{abs} - T_{amb})}{I_{\!_T}}}
	\label{hottel-whiller-eq0}
\end{equation}

\noindent where $\rm{U_{\!_L}}$ is the collector's overall heat loss coefficient (W/(m$^2$.\textdegree C)) and both absorber and ambient temperatures ($\rm{T_{abs}}$ and $\rm{T_{amb}}$) are in \textdegree C. The $\rm{U_{\!_L}}$ value depends weakly on temperature, and, in most cases, it is considered constant at typical operating conditions (\cite{Rabl1985}). Lastly, the optical efficiency $\eta_{\rm{o}}$ is the ratio between the absorbed and the incident solar radiation. From this equation, $\eta_{\rm{th}}$ can be plotted against $\rm{(T_{abs} - T_{amb})/I_{\!_T}}$, resulting in a linear curve, with $\eta_{\rm{o}}$ and $\rm{{U_{\!_L}}}$ as the linear coefficient and the slope, respectively (\cite{Goswami2015}). 

Another way to calculate the efficiency is based on the air temperature, particularly $\rm{T_{in}}$ and $\rm{T_{out}}$ at the inlet and outlet of the collector, respectively (\cite{Duffie2013}). Eq. (\ref{hottel-whiller-eq0}) can be rewritten by adding a multiplicative term known as the heat removal factor or heat exchange effectiveness. It is defined as the ratio of the heat transferred to the airflow to the maximum possible heat transfer if the outlet air temperature was heated to the absorber surface temperature (\cite{Kutscher1994}). In practice, as the air temperature approaches the absorber temperature, the heat transfer rate slows, requiring infinitely large surface areas or time to achieve the maximum possible heat transfer. This effectiveness is calculated as follows:

\begin{equation}
	\mathrm{\varepsilon_{\!_{HX}} = {\frac{{{T_{out}} - {T_{in}}}}{{{T_{abs}} - {T_{in}}}}}}
	\label{heat-exchange}
\end{equation}

This effectiveness can also be written as a function of the airflow rate and the convective heat transfer coefficient ($\rm{h_{\!_{HX}}}$):

\begin{equation}
	\mathrm{\varepsilon_{\!_{HX}} = 1 - exp\left(-\frac{h_{\!_{HX}}A_{abs}}{m_{air}C_{p,air}}\right)}
	\label{effectiveness}
\end{equation}

\noindent where this convective coefficient $\rm{h_{\!_{HX}}}$ (W/(m$^2$.\textdegree C)) considers the heat transfer mechanism between the airflow and the hot absorber plate. It is related to the Nusselt number, which is the ratio of convective to conductive heat transfer (\cite{Incropera2006}). This is calculated by Eq. (\ref{Nusselt}):
	
\begin{equation}
	\mathrm{Nu = \frac{L_c}{k_{air}}{h_{\!_{HX}}}}
	\label{Nusselt}
\end{equation}

\noindent where $\rm{L_c}$ is the characteristic length of the heat transfer (m) and $\rm{k_{air}}$ is the air thermal conductivity (W/(m.\textdegree C)). The Nusselt number is usually a function of the Reynolds number, which is proportional to the air velocity. Therefore, operating a solar collector with higher airflow rates is desirable to enhance heat transfer. In addition to that, many other factors influence the heat transfer mechanism. The following section describes the elements of a SAHC and how they influence its thermal performance. These elements are the absorber plate, glazing cover, air flow rate and system modifications.

\subsection{Effect of absorber surface}  

As the airflow to be heated goes through a perforated absorber surface, the heat transfer mechanism between the holes and the air is more effective compared to flat plate collectors. The absorber design considers the following factors: i) material and coatings, ii) shape, iii) thickness of the absorber, and iv) modified area.

\subsubsection{Absorber material and coatings} 

It was previously assumed that a collector's high performance resulted from highly thermally conductive materials. This assumption was based on the fact that a significant portion of the thermal energy was transferred to the airflow. Plus, it would considerably increase the average surface temperature and, consequently, the radiative heat loss to the ambient (\cite{Gawlik2002}; \cite{Gawlik2005}).

\citet{Christensen1997} compared experimentally the thermal performance of an UTSC for two absorber materials: aluminium (k = 216 W/(m.K)) and styrene plastic (k~=~0.16~W/(m .K)), where both surfaces had the same geometry. Results show that the UTSC's efficiency is relatively insensitive to low thermal conductivity materials. This means sufficient thermal energy is from the absorber surface to the air, so high thermal conductivity materials are not as critical as previously assumed.

\citet{Arulanandam1999} simulated a UTSC's thermal performance in CFD under no wind conditions, varying the absorber's thermal conductivity from 0.196 to 15.121~W/(m.K)). They concluded that, for low porosity plates, the heat exchange effectiveness dropped by 10 -- 20\%, but the thermal efficiency only decreased by approximately 5\%.

The temperature distribution along the absorber surface can vary for low-conductive materials. The local convective heat transfer is higher in regions of higher surface temperature and lower in regions of lower surface temperature. This effect is reduced if the hole pitch is small so that a large temperature gradient is not achieved. \citet{Gawlik2005} showed that the effect of material conductivity on thermal performance is negligible. The study then concluded that low thermal conductivity materials can be used with no thermal efficiency penalty but a significant benefit in cost savings and corrosion resistance.

One or both of the front and back surfaces of the absorber may be dark in colour to absorb solar radiation. Surfaces may be treated or coated to have a low emittance of infrared radiation to reduce heat losses. The effect of the radiative properties absorptivity and emissivity has also been reported. \citet{Leon2007} simulated a UTSC varying the values of both properties and found that absorptivity substantially affects thermal efficiency more than emissivity. \citet{El-Sebaii2010} simulated a single-pass GAHC comparing absorber surfaces using different coatings. They concluded that the highest daily efficiency was achieved using nickel–tin (absorptivity and emissivity of 0.98 and 0.14). Compared to a black-painted galvanized iron absorber (0.88 of absorptivity and emissivity), the nickel-tin coated absorber outperformed by 29.23\%. \citet{Li2016} simulated a glazed TSC and found that painting the absorber plate with a selective coating of higher absorptivity and lower emissivity would enhance the heat transfer mechanism from the absorber plate to the plenum and reduce the radiative losses from the absorber surface to the glazing cover. The effect of coating absorptivity on thermal efficiency is more considerable than emissivity's.

\subsubsection{Effect of porosity, perforation diameter and pitch} 

The plate porosity for flat plates is defined as the ratio of perforation area to the total surface area. It can only be calculated by setting values of perforation diameter and pitch. Smaller perforation diameters strengthen the jet impingement and thus increase the heat transfer mechanism (\citet{Li2016}). The pitch (or perforation spacing) more substantially influences heat exchange effectiveness than thermal efficiency. With larger pitches, hot spots tend to develop on regions of the absorber surface away from the perforations (\citet{Arulanandam1999}). However, this effect can be avoided if the distance between the holes is small enough.

\citet{Kutscher1994} investigated the effect of increasing perforation diameter (1.6 mm to 3.2 mm) and pitch (13.5 mm to 27 mm) and verified that the heat exchange effectiveness decreased. \citet{Arulanandam1999} discovered that the Nusselt number was increased in a range of plate porosity from 0.5\% to 2\%. \citet{Decker2001} simulated an UTSC and found that the heat exchange effectiveness decreased with increasing pitch (7 mm to 24 mm) and perforation diameter (0.8 mm to 3.6 mm). They also concluded that 28\% of the air temperature rise occurs in holes of the perforated plate. \citet{Gawlik2005} tested two plates of different porosities (0.3\% and 5\%) and concluded that there was no significant difference in air temperature rise because the perforation diameter was increased and the pitch was decreased by the same proportion. 

According to \citet{Leon2007}, simulation results showed that the airflow temperature rise and heat exchange effectiveness increased with decreasing pitch and perforation diameter. For a constant solar radiation and airflow rate, changing the pitch from 12 to 24 mm with a corresponding change in perforation diameter from 0.8 mm to 1.55 mm resulted in a drop of 5.5 $^{\rm o}$C in the airflow temperature rise. Furthermore, when the porosity was increased, the effectiveness and the thermal efficiency decreased.

\subsubsection{Effect of absorber thickness}   

The effect of the absorber thickness on thermal effectiveness is insignificant when it is smaller than 1.5 mm (\cite{Kutscher1994}). However, for thick absorbers (between 1.6 and 3.6 mm), the heat transfer varies between different perforation areas, thus affecting the collector's thermal performance. \citet{Zomorodian2012} tested UTSCs with two different absorber plate thicknesses and concluded that the thicker was more efficient.

\subsubsection{Effect of the absorber-modified area}

One way to enhance the heat transfer from the absorber to the airflow is to introduce obstacles in the air stream to increase the absorber surface area. These obstacles can be fixed either on the internal face of the absorber, on the back plate or as a combination. These obstacles aim to increase the outlet air temperature and efficiency with minimum losses (\cite{Karsli2007}). Modifications of the absorber area include using finned, wavy, or V-corrugated shapes, as seen in Figure \ref{modified}.

\Figure[scale=0.62,placement=!ht,label={modified},caption={Illustration of GAHCs with different absorber areas: (a) wired, (b) wavy, (c) finned, and (d) V-shaped (or V-corrugated). From \citet{Pottler1999}.}]{figs/modified_area.png}

\citet{Karim2004} studied and compared three types of GAHCs: flat plate, finned and V-corrugated to achieve an efficient design suitable for a solar dryer. They found that the V-corrugated collector is the most efficient and the flat plate one the least. Results show that the V-corrugated collector has 7 -- 12\% higher efficiency than flat plate collectors. \citet{Kurtbas2004} also studied different absorber geometries and concluded that all GAHCs outperform the flat plate collector. \citet{Karsli2007} compared the thermal performance of a finned absorber collector to a flat plate one with no fins and concluded that the finned GAHC is more efficient than the flat plate. This is because the fins create turbulent flow, which leads to a higher heat transfer coefficient, lowering the absorber temperature and reducing the thermal heat loss at the same time. \citet{Alta2010} compared a GAHC with a flat absorber surface to one with a finned absorber and concluded that attaching fins on that surface increases the thermal efficiency. \citet{Assari2011} developed a mathematical model based on the effectiveness method for assessing the thermal performance of a GAHC, where water and air flow simultaneously. Three different channels were used to enhance the collector's performance: rectangular fin, triangular fin (V-corruated) and without fin. Simulation results show that channels with rectangular fins performed the best. \citet{ElSebaii2011} compared the thermal performance of a flat plate collector to a V-corrugated collector. The results showed that the double-pass V-corrugated plate collector is 11 -- 14\% more efficient than the double-pass flat plate collector.

\subsection{Effect of glazing cover} 

A glazing cover plays an important role in suppressing convective heat losses from the absorber plate to the ambient and protecting the solar collector against weather conditions. It also needs to have high transmissivity to the solar spectrum and be extensively opaque to long (or infrared) wavelength radiation emitted by the absorber (\cite{Saxena2015a}). In other words, a glazing cover reduces convective and radiative heat losses while transmitting most incoming solar radiation (\cite{Norton2006}).

Glazing materials commonly used are glass, plastic, and fibreglass. The challenge is to find a material with high transmissivity and low thermal conductivity that is affordable and has the required mechanical properties for building integrated systems. Glass is considered a glazing cover because it is transparent in the solar range and absorbs almost all the infrared radiation re-emitted by the absorber plate. This enhances the collector's thermal efficiency by creating a greenhouse effect (\cite{Khoukhi2006}).

More than one glazing cover may be used to minimise the heat losses from the collector (\cite{El-Sebaii2010}; \cite{Yeh2009}). However, the transmissivity decreases due to increased reflections (\cite{Michalopoulos1994}). \citet{Alta2010} conducted an experimental study comparing a single and double-glazed flat plate collector with a finned absorber. The authors stated that the double-glazed collector performed better and showed a higher air temperature difference.

Reflection losses at the glazing surface depend on the refractive index of the cover material and the structural orientation of the glazing. The lowest reflection losses can be achieved if an antireflective coating with a refractive index between the air and the cover material is used. Investigations have shown that the glass transmittance and solar collector efficiency can be increased by 4\% if an antireflection coating is applied instead of standard glass as the cover plate for the solar collector (\cite{Furbo2003}).  

Glass is also very resistant to scratching and high operating temperatures and practically impervious to the damaging effects of ultraviolet exposure. The incident sunlight transmitted through glass depends on the iron content of the glass, which varies between 85\% and 92\% at normal incidence. While low iron content increases the transmittance of glass, low iron glass is more expensive. Glass can be easily broken, but this can be minimized by using tempered glass, which adds a further cost (\cite{Duffie2013}).

Transparent plastics, such as polycarbonates, polyethylene and acrylics have also been used as glazing materials (\cite{Koyuncu2006}). Their main advantages are resistance to breakage and light weight, and are cheaper than glasses. Their main advantages are resistance to breakage, they are lightweight, and they are cheaper than glasses. The main disadvantages of plastics are high transmittance in the longer wavelength, and deterioration over time due to ultraviolet solar radiation (\cite{Goswami2015}; \cite{Duffie2013}). Additionally, plastics are generally limited in the temperatures they can sustain without deteriorating or undergoing dimensional changes. Although glass is expensive, this is the best glazing material considering 20 years of collector life span (\cite{Shams2013}).

\subsection{Effect of airflow rate}  

The flow rate is the most important factor in the thermal performance of a solar collector. The effects of that have been extensively studied. Experimental and simulation results show that more useful heat is collected when the flow rate increases and overall losses are reduced, thus increasing the collector's thermal efficiency. On the other side, the outlet temperature and the heat exchange effectiveness are decreased (\cite{Christensen1997}; \cite{Ammari2003}; \cite{Leon2007}; \cite{El-Sebaii2010}; \cite{Zomorodian2012}; \cite{Li2016}). A typical relationship between air temperature rise, thermal efficiency and flow rate is shown in Figure \ref{airflow_effect}.

\Figure[scale=0.70,placement=!ht,label={airflow_effect},caption={Graphs of air temperature rise and thermal efficiency against mass flow rate at the steady state. From \citet{Tyagi2012}.}]{figs/airflow_effect.png}

\citet{Ammari2003} simulated a single-pass GAHC and found that the thermal efficiency increased until a certain level of volumetric flow rate, and then it increased at a lower rate. A decreasing pattern could be observed for the air temperature as the flow rate was increased. \citet{Leon2007} simulated a UTSC and observed that the decrease in energy rate is lower at lower approach velocities. They also concluded that the collector efficiency decreases with increasing outlet air temperatures. \citet{Jafarkazemi2013} simulated a flat plate collector and also observed that the overall heat loss coefficient dropped as the mass flow rate increased. \citet{Badache2014} and \citet{Nowzari2015} analysed different factors affecting UTSC and GAHC performances and concluded that the airflow rate strongly influenced thermal efficiency. \citet{Li2016} evaluated the performance of a GAHC with a perforated absorber, considering the fan power required to overcome airflow resistance through the collector. In this case, higher airflow rates lead to higher useful heat collected and fan power required. Results show that there is a level of airflow rate that maximises energy efficiency.

\subsection{System modification}

This topic depicts the influence of the airflow passing through the collector in contact with the absorber, the parameterisation of the channel dimension through which the air flows, and how multiple collectors are connected (series or parallel).

\subsubsection{Air passage through the collector}

Considerations are given to the airflow contact with the absorber plate (or PV module) when the former passes through the collector. A single-pass collector is when the airflow comes into contact with the absorber only once. Alternatively, it is double-pass collector when air flows in contact with the absorber twice, as shown in Figure \ref{double_pass}. 

\Figure[scale=0.85,placement=!ht,label={double_pass},caption={Illustration of (a) single pass and (b) double pass air heating collector. From \citet{Hegazy2000}.}]{figs/double_pass.png}

\citet{Hegazy2000} simulated a photovoltaic/thermal (PV/T) glazed collector using different modes: air flowing over or below the absorber and even on both sides in a single or in a double pass. The author found out that flowing air on both sides leads to the best performance, considering both applications. \citet{Yousef2008} tested single and double-pass GAHCs and concluded that double-pass achieved higher thermal efficiency and outlet air temperature. \citet{Nowzari2015} investigated a single and double-pass GAHC and concluded that higher efficiencies are achieved using the double-pass mode. \citet{Karim2004} investigated collectors with different absorber configurations. From the efficiency tests in double-pass operation, it is concluded that the efficiency of all collectors increases in double-pass mode.

The effect of external recycling on the GHAC thermal efficiency has been investigated. If operated with an external recycle, the collector's thermal performance is considerably improved, and the desirable effect overcomes the drawbacks. The performance is enhanced with increasing reflux ratio, especially for operating at a lower air flow rate with higher inlet air temperature (\cite{Yeh2009}).

\subsubsection{Channel's dimensions}

\citet{Hegazy1999} showed a criterion for determining the channel's optimum depth-to-length ratio, which maximises the useful energy from GAHCs to operate at a fixed mass rate of airflow. The author also observed that decreasing the depth or increasing the length improves the thermal performance. \citet{Tonui2007} studied a photovoltaic/thermal glazed collector where forced air was used to extract heat from the back of the PV module through a channel. They evaluated the effect of the channel depth (distance between the PV module and the collector's bottom) and the length on the thermal performance at a constant airflow rate. It was verified that the thermal efficiency and air outlet temperature were reduced with increasing channel depth. They also concluded that the thermal efficiency increased with increasing channel length and approached a constant value as the length increased. The same pattern was verified by \citet{Yousef2008} when they investigated the thermal performance of a single-pass GAHC where forced air was pumped above the absorber plate. They also concluded that air temperature and efficiency decreased with increasing channel depth at a constant airflow rate. \citet{Tonui2008} simulated a photovoltaic/thermal glazed collector using natural convection to alleviate the PV module temperature. They found that there is an optimum channel depth that maximises thermal efficiency.

\subsubsection{Connection of collectors}

Solar collector arrays can be connected in series or parallel, each with different thermal performance outcomes. In a series connection system, the total heat transfer of the collectors is higher since the total airflow passes through all collectors. However, the temperature rise in the collectors reduces the thermal efficiency of each progressive collector, and the power consumption to pump the airflow is also higher (\cite{Hastings2000}). A schematic of multiple units in connection is shown in Figure \ref{series-parallel}. 

\Figure[scale=0.65,placement=!ht,label={series-parallel},caption={Schematics of a system with collectors in series and parallel. From \citet{Fanney1981}.}]{figs/series-parallel.png}

\citet{Oonk1979} developed a formula to predict the performance of N collectors in series by deriving the exit temperature of one collector and using it as the inlet temperature of the next collector. \citet{Fanney1981} also developed an equation to predict the thermal performance of collector arrays, both in series and parallel, based on energy balance.

\section{Concentrating collectors}

When it is required to warm the airflow to higher temperatures with high thermal performance, concentrators can be employed to meet the objective. The working principle is to receive solar radiation through a larger area and direct that, using reflectors, to a smaller absorber area. There are different types of concentrating collectors, depicted as follows (\cite{Evangelisti2019}): 

\begin{itemize}
	\item Parabolic trough collector (PTC): consists of a parabolic reflector and an absorber placed along the whole length of the concentrator at the parabola's focus. PTCs generally track the Sun using east-west, north-south, or polar orientations. The absorber is usually tubular and enclosed in a glass tube to reduce radiative and convective losses (\cite{Goswami2015}). The solar radiation is reflected torward the tube, bringing it to high temperatures and heating the heat-transfer fluid that flows inside it. The absorber temperature varies between 50 $^{\rm{o}}$C and 300 $^{\rm{o}}$C, but it can also reach \mbox{400 $^{\rm{o}}$C};
	
	\item Compound parabolic concentrator (CPC): A CPC consists of two distinct parabolic segments, with each segment's focus positioned at the opposite end of the absorber surface. The axes of these parabolic segments are tilted away from the CPC's central axis by the acceptance angle $\theta_{{\rm{acc}}}$;
	
	%It is designed from two distinct parabolic segments, where the focus of each one is located at the opposing absorber surface end points. The axes of the parabolic segments are oriented away from the CPC axis by the acceptance angle $\theta_{{\rm{a}}}$. The slope of the reflector surfaces at the aperture is parallel to the optical axis for untruncated CPCs;
	
	\item Heliostat field collector: composed of flat reflectors placed all around a central receiver, called solar tower. These reflectors can face the Figure through a tracking system. Central receivers can achieve temperatures of 1000 $^{\rm{o}}$C or even higher. Therefore, a heliostat collector is suitable for thermal electric power production of 10 -- 1000~MW (\cite{Goswami2015});
	
	\item Linear Fresnel collector: comprised of linear receivers and reflectors. The reflector segments are aligned horizontally, facing the Sun so that the rays can hit the receiver without needing movement;
	
	\item Parabolic dish collector: characterized by a paraboloidal geometry that concentrates solar radiation onto a receiver placed at the focal point of the collector.
	
\end{itemize}

\subsection{Optical analysis}

One way of evaluating a concentrator is by characterising its optical performance. Optical efficiency is defined as the ratio between the absorbed and the incident solar radiation. For this analysis, the optical properties of the reflectors, glazing cover and absorber should be taken into consideration, as well as the reflectors' shape and the concentration ratio (\cite{Sellami2013}):

\begin{equation}
	\mathrm{\eta_o = {\tau_{col}}\tau_{glaz}\alpha_{abs}}
	\label{optical0}
\end{equation}

\noindent where the term $\rm{\tau_{col}}$ considers the number of reflections at the reflectors. The reflector's shape and concentration ratio dictate the number of reflections and, consequently, the optical efficiency. The term $\rm{\tau_{glaz}}$ is the transmissivity of the glazing cover; alternatively, for collectors without cover or glass-tube absorbers, this term is unity. The term $\rm{\alpha_{abs}}$ is the absorptivity of the absorber plate. Therefore, it is desirable that the concentrator transmits most of the solar radiation through the glazed aperture, has a highly reflective reflector surface, and has a high absorptivity absorber with low emissivity. Most of these properties have been discussed in the previous section of this Chapter.

Other factors are taken into consideration: i) incoming solar radiation and its components; ii) the position of the Sun at a specific location and what direction the concentrator is facing at a set inclination; iii) the optics in the glazing cover, and; iv) the effect of truncation. Other factors, such as the parabolic shape of a CPC collector and concentration ratio, will be further investigated in another section.

%The shape of reflectors affects size, angular acceptance range (\cite{Zacharopoulos2000}; \cite{Harmim2012}) and maximum geometric concentration ratio (\cite{Mills1978}). Given the same level of concentration ratio, concentrators of narrow angular acceptance are more efficient so collect higher amounts of the available solar energy (\cite{Sarmah2011}; \cite{Kostic2012}).

%A concentrator is usually truncated. Less reflector material is then required which reduces costs and weight. Figure \ref{untruncated} shows the untruncated and truncated versions of the same concentrator. The effect of truncation on the design parameters concentration ratio, height-aperture width ratio and reflector length has been presented by graphs and equations (\cite{McIntire1979}; \cite{Rabl1976}). Figure \ref{ang_acc} shows the angular acceptance function for an untruncated (full) CPC and for a truncated configuration.
%
%\Figure[scale=0.40,placement=!ht,label={untruncated},caption={Truncated and untruncated CPC with a tubular absorber.}]{figs/untruncated.png}
%
%\Figure[scale=0.60,placement=!ht,label={ang_acc},caption={Angular acceptance function of a full and truncated CPC. Adapted from \citet{Norton1991}.}]{figs/ang_acc2.jpg}
%
%\citet{Carvalho1985} derived analytic expressions of angular acceptance range and evaluated the yearly collectable energy as function of the extent of truncation. Truncated concentrators accept solar rays at broader incident angles, thus collecting more solar energy due to reduction of reflections. \citet{Francesconi2018} simulated a five-CPC assembly's performance in CFD; they concluded that a concentration ratio reduction from 2.0 to 1.96 resulted in a 2\% increase of the system's thermal efficiency.

\subsubsection{Solar radiation and intercept factor}

The total solar radiation ($\rm{I_{\!_{T}}}$) incident on the concentrator's aperture is the sum of the beam ($\rm{I_{\!_{B}}}$) and diffuse ($\rm{I_{\!_{D}}}$) components (W/m$^{2}$). However, since concentrators exploit only part of the diffuse radiation, which is dependent of the collector's concentration ratio CR, the factor $\Gamma$ must be defined as the fraction of total solar radiation accepted. Assuming that the angular distribution of diffuse radiation is isotropic, this factor can be estimated as (\cite{Rabl1980}):

\begin{equation}
	\mathrm{\Gamma  = \frac{\displaystyle {\left( {{I_{\!_B}} + \frac{{{I_{\!_D}}}}{CR}} \right)}}{{{I_{\!_T}}}}}
	\label{xi}
\end{equation} 

\noindent and therefore the incoming solar radiation available to reach the absorber surface is assumed to be $\rm{I_{\!_T}\Gamma}$. Since CPC collectors operate in the concentration ratio range of 2 to 10 to capitalise on the corresponding reduced tracking requirement, diffuse radiation is accepted by one-half to one-tenth of the incident (\cite{Goswami2015}). 

It is important to highlight other angular distributions of the diffuse insolation that can affect the performance of PTC and CPC collectors. Two other particular distributions can be considered: cosine and hybrid Gaussian. The hybrid Gaussian distribution combines an isotropic background with a circumsolar Gaussian part. This distribution is more realistic for a tracking system than the isotropic model (which underestimates the insolation intensities at incidence angles near zero) and the cosine model (which underestimates the intensities at large incidence angles). The analytical expressions for the three distributions considered have been presented by \citet{Prapas1987}. However, on clear days (diffuse radiation is approximately 11\% of total radiation), the difference in optical efficiency between the three distributions of diffuse radiation is insignificant.

\subsubsection{Collector's inclination and orientation}

It is important to establish the position of the collector's aperture considering its inclination concerning the horizontal plane and the Sun's position as a function of the day, time and location. Figure \ref{Figure_orientation} shows a basic scheme of the Sun's position by the altitude ($\rm{a_s}$) and azimuth ($\rm{\gamma_s}$) solar angles, as well as the inclination $\beta$ and the collector azimuth angle $\rm{\gamma_{col}}$. The latter defines the orientation of the collector: if $\rm{\gamma_{col}} = 0$, the collector is south-facing.

\Figure[scale=0.80,placement=!ht,label={Figure_orientation},caption={(a) Altitude solar angle, surface azimuth angle, and solar azimuth angle for an inclined surface. (b) Plan view showing solar azimuth angle. Adapted from \citet{Duffie2013}.}]{figs/Figure_orientation.png}

The incident angle $\theta_{\rm{i}}$, defined as the angle between the incident solar ray and the normal to the aperture, is calculated by Eq. (\ref{incidence0}):

\begin{equation}
	\mathrm{\theta_i = {\cos ^{-1}}\left[ {\cos {a_s}\cos ({\gamma_s} - {\gamma_{col}})\sin \beta  + \sin {a_s}\cos \beta} \right]}
	\label{incidence0}
\end{equation}

Solar hour angles ($\omega_{\rm{s}}$) were obtained from the solar time for each day of operation. The solar altitude and solar azimuth angles were calculated from (\cite{Duffie2013}):

\begin{equation}
	\mathrm{{a_s} = {\sin ^{ - 1}}\left( {\sin \phi \sin {\delta _s} + \cos \phi \cos {\delta _s}\cos {\omega_s}} \right)}
	\label{solar_alt0}
\end{equation}
\vspace*{-0.5cm}
\begin{equation}
	\mathrm{\gamma_s = {\sin^{-1}}\left(\frac{\cos \omega_s \sin \delta_s}{\cos a_s}\right)}
	\label{azimuth0}
\end{equation}

\noindent where the solar declination $\delta_{\rm{s}}$ is a function of the year's day and $\phi$ is the location's latitude.

\citet{Pottler1999} calculated the total energy collected for a GAHC at north, south, west and east orientations located in the Northern Hemisphere and verified that the south-facing orientation collects more energy because it is optically more efficient. \citet{Roux2016} used a ray tracing simulator to calculate a flat plate collector's optimum inclination and azimuth angle at different locations. Results showed that an optimally positioned collector can, on average, collect 10\% more annual solar energy than a horizontally fixed collector. The optimum fixed inclination angle is similar to the location's latitude, and the optimum fixed azimuth angle is a function of the longitude angle minus the absolute latitude angle.

\subsubsection{Glazing optics}

By Snell's law, considering the angle of incidence at the glazing cover ($\theta_{\rm{i}}$), the angle of refraction is calculated by Eq. (\ref{snell}):

\begin{equation}
	\mathrm{\theta_r = arcsin\left(\frac{sin\theta_{i}}{n_{idx}} \right)  }
	\label{snell}
\end{equation}

\noindent where $\rm{n_{idx}}$ is the refraction index of the glazing cover dependent of the material. When passing through the glazing medium, part of the incident radiation is reflected and absorbed. The term that takes into account the reflected radiation alone is given by Eq. (\ref{rho_glaz}):

%\begin{equation}
%	\mathrm{r_{par} = \frac{tan^2(\theta_r - \theta_i) }{tan^2(\theta_r + \theta_i) } }
%	\label{parallel}
%\end{equation}
%
%\begin{equation}
%	\mathrm{r_{perp} = \frac{sin^2(\theta_r - \theta_i) }{sin^2(\theta_r + \theta_i) } }
%	\label{perpend}
%\end{equation}

\begin{equation}
	\mathrm{\rho_{glaz} = \frac{1}{2}\left[\frac{1 - r_{par}}{1 + (2N_c - 1)r_{par}} + \frac{1 - r_{perp}}{1 + (2N_c - 1)r_{perp}}\right]}
	\label{rho_glaz}
\end{equation}

\noindent where $\rm{N_c}$ is the number of glazing covers, and $\rm{r_{par}}$ and $\rm{r_{perp}}$ are the unpolarized components of the radiation, functions of the angles of incidence and refraction (\cite{Duffie2013}). Similarly, the term that considers the glazing absorptivity $\rm{\alpha_{glaz}}$ is given by Eq. (\ref{abs_glaz}):

\begin{equation}
	\mathrm{\alpha_{glaz} = exp\left(-\frac{K_{ext}\delta_{glaz}}{cos\theta_r} \right) }
	\label{abs_glaz}
\end{equation}

\noindent where $\rm{\delta_{glaz}}$ is the glazing thickness and $\rm{K_{ext}}$ is the extinction coefficient which is a function of the material: for glass, the value of this coefficient varies from approximately 4 m$^{-1}$ for ''water white'' glass to nearly 32 m$^{-1}$ for high iron oxide content (greenish cast of edge) glass. Lastly, the glazing transmissivity $\rm{\tau_{glaz}}$ can be approximated by the product of the glazing absorptivity and the standalone transmissivity as a function of the glazing material and the incidence angle:

\begin{equation}
	\mathrm{\tau_{glaz} \cong \rho_{glaz}\alpha_{glaz}}
	\label{transmi}
\end{equation}

\subsubsection{End losses}

If a linear concentrator is long in an east-west orientation compared to its width and height, it can be assumed to behave as a two-dimensional system where end effects are negligible (\cite{Eames1993a}). The optical analysis must include the end losses for concentrators with short axial lengths, as some reflected solar rays might not reach the absorber under certain obtuse solar incident angles. To account for the end losses, the optical efficiency is multiplied by a factor for that purpose, which is a function of the incidence angle and the collector's geometry. This factor was analytically calculated for imaging parabolic troughs (\cite{Rabl1985}) and linear Fresnel concentrators. End losses have a more substantial influence at high-latitude locations, which could cause the absorber to be entirely in shadow on winter days (\cite{Hongn2015}). \citet{Pu2011} estimated the end-effect for the north-south and east-west linear Fresnel collectors, analyzing the angles between incident solar rays and the tacking axes of the reflectors. They concluded that the end losses can be compensated by increasing the length of the mirror field. \citet{Heimsath2014} quantified optical losses of Fresnel collectors and proposed a corrective end loss factor for end loss modelling. They also observed that the optical losses are higher for wider zenith angles and shorter collectors. \citet{Xu2014} presented an optical analysis and compensation method for the end loss effect of parabolic trough solar collectors with a horizontal north-south axis. The calculation formulae for optical end loss ratio and increased optical efficiency are derived, and various factors affecting them are analyzed. The compensation method is found to be applicable for regions with latitudes over 25$^{\rm{o}}$ and short trough collectors.

\subsubsection{Truncation}

Compared to a simple parabola, a CPC is very deep, and therein lies its main disadvantage: it requires a relatively large reflector area for a given aperture area. For example, for a concentration ratio of 10, the ratio of reflector area to aperture area is approximately 11, while a PTC has a ratio of around 1.2. To overcome this drawback, a large portion of the top of a CPC can be cut off with almost no loss in performance. A CPC will almost always be truncated in practical applications for economic reasons (\cite{Rabl1976}). \citet{Carvalho1985} derived analytic expressions of the angular acceptance range and evaluated the yearly collectable energy as a function of the extent of truncation. Truncated concentrators accept solar rays at broader incident angles, thus collecting more solar energy due to reduced reflections. \citet{Francesconi2018} simulated a five-CPC assembly's performance in CFD; they concluded that a concentration ratio reduction from 2.0 to 1.96 resulted in a 2\% increase in the system's thermal efficiency.

\subsection{The Compound Parabolic Concentrator (CPC) family}

This section depicts the geometry of a symmetric CPC and an asymmetric CPC, as well as a modification to include an inverted absorber.

\subsubsection{Symmetric CPC} 

The compound parabolic concentrator (CPC) is a non-imaging solar concentrator that has the advantages (compared to focusing ones) of i) no need for solar tracking and ii) the ability to collect a portion of diffuse radiation (\cite{Winston1974}). The CPC has been used for heating and PV electricity production (\cite{Jaaz2017}). A typical CPC cross-section is shown in Figure \ref{CPC1}. Solar radiation accepted within the angular acceptance range is focused onto an absorber by reflection at the two symmetrical parabolic reflectors. 

\Figure[scale=0.60,placement=!ht,label={CPC1},caption={Basic CPC with flat plate absorber: (a) cross-section design in 2D and (b) in 3D. From \citet{Duffie2013} and \citet{Winston1974}.}]{figs/CPC-2D-3D.png}

One of the geometric parameters of a CPC is the geometrical concentration ratio, which is the ratio of the aperture to the absorber areas. This parameter has an upper limit calculated by Eq. (\ref{CR}):

\begin{equation}
	\mathrm{CR = \frac{1}{sin\theta_{acc}}}
	\label{CR}
\end{equation}

\noindent where the half-acceptance angle $\rm{\theta_{acc}}$ is the angular limit over which radiation is fully accepted without moving all or part of the concentrator (\cite{Rabl1976a}). If the reflectors are specular, all the solar rays incident at angles within the acceptance range (between $\pm \theta_{\rm{acc}}$) reach the absorber surface. Figure \ref{untruncated} shows the untruncated and truncated versions of the same CPC. The effect of truncation on the design parameters concentration ratio, height-aperture width ratio and reflector length has been presented by graphs and equations (\cite{McIntire1979}; \cite{Rabl1976}). Figure \ref{ang_acc} shows the angular acceptance function for an untruncated (full) CPC and a truncated configuration.

\Figure[scale=0.40,placement=!ht,label={untruncated},caption={Truncated and untruncated CPC with tubular absorber. From \citet{Norton1991}}]{figs/untruncated.png}

\Figure[scale=0.60,placement=!ht,label={ang_acc},caption={Angular acceptance function of a full and truncated CPC. Adapted from \citet{Norton1991}.}]{figs/ang_acc2.jpg}

The shape of reflectors affects the size, angular acceptance range (\cite{Zacharopoulos2000}; \cite{Harmim2012}) and the maximum geometric concentration ratio (\cite{Mills1978}). Given the same level of concentration ratio, concentrators of narrow angular acceptance are more efficient, so they collect higher amounts of the available solar energy (\cite{Sarmah2011}; \cite{Kostic2012}).

The CPC has been extensively studied and reported in the literature. A common case of study considered a CPC where a working fluid passes within the absorber to capture the heat. However, the cavity between the absorber and the glazing cover is filled with dead air, and therefore, convective losses occur due to the temperature gradient. This affects the motion of air, known as natural or free convection. Hence, this free convective heat transfer coefficient $\rm{h_f}$ (W/m$^2$) is calculated as:

\begin{equation}
	\mathrm{h_f = \frac{{{k_{air}}}}{{{L_c}}}Nu_{f} = a{(Ra)^b}}
	\label{hn}
\end{equation}

\noindent where $\rm{Nu_f}$ is the Nusselt number for free convection, the parameters a and b depend on the geometry and the flow regime (\cite{Cengel2005}) and the Rayleigh number is defined as the strength of the thermal buoyancy against the viscous and thermal diffusion.

%The Rayleigh number is defined as the product of the Grashoff and the Prandtl numbers, shown by Eq. (\ref{Ra}):
%
%\begin{equation}
%	\mathrm{Ra = Gr \Pr = {\frac{{g{\beta_{th}}}}{{\nu_{air}^2}}{L^{3}_c}\Delta T^{*}\Pr}}
%	\label{Ra}
%\end{equation}
%
%\noindent where: $\rm{L_{c}}$ is the characteristic length; the volume expansion coefficient $\beta_{\rm{th}}$ is 1/$\rm{T_{air}}$ as the air is considered an ideal gas; $\rm{\Delta T^{*}}$ is the temperature difference between the surface and the air; and $\nu_{\rm{air}}$ is the air kinematic viscosity.

\citet{AbdelKhalik1978} evaluated the natural convective coefficients between the absorber surface and cover plate for vertically oriented two-dimensional CPC using finite-element techniques. The critical Rayleigh number values for different concentration ratios (2 $<$ CR $<$ 10) with three levels of truncated CPCs are determined. Results show that convection is suppressed in high-concentration cavities with a large height/aperture ratio.

%Mathematical formulations were developed to study thermal processes in a compound-parabolic- concentrator (CPC) collector. The system under investigation consists of a CPC cusp fitted with a concentric, evacuated double pipe to serve as a heat absorber. Heat is transmitted to the circulating fluid flowing inside a U-tube via the heat getter slipped inside the inner pipe (\cite{Hsieh1981}).

\citet{Prapas1987} developed a heat transfer model and found out that the Nusselt number is affected by the concentration ratio of the collector, its inclination and the absorber temperature. The average Nusselt number rises as the inclination of the collector increases, and this effect is enhanced for higher concentration ratios. Moreover, generalised correlations for the variation of the Nusselt number have been obtained.

\citet{Eames1993} performed a detailed parametric heat transfer analysis in untruncated CPCs using a model for their optical and thermal behaviour. The effects of inclination and acceptance angles on free convection within the cavity were studied. A convective heat transfer correlation is obtained for the average Nusselt number concerning the Grashof number that considers acceptance angle and angular inclination. They also observed that CPCs of higher acceptance angles have lower Nusselt numbers.

A theoretical and experimental investigation into the modifications in optical and thermal performance resulting from introducing a baffle into the cavity of a CPC has been performed. Results show that introducing a baffle reduces internal convection, reducing heat losses with a slight reduction in optical efficiency (\cite{Eames1995}).
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

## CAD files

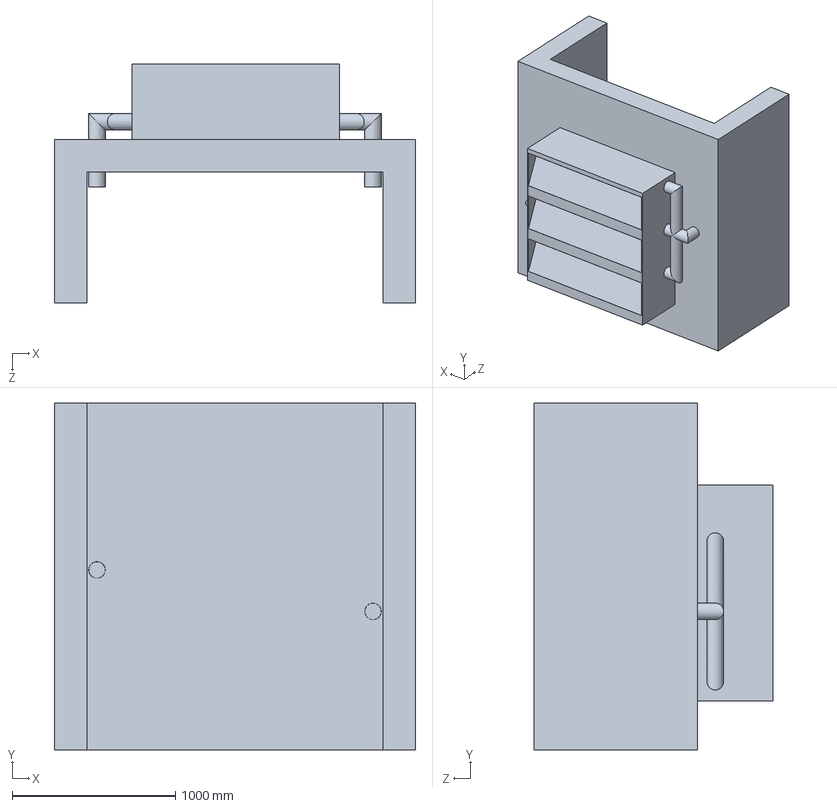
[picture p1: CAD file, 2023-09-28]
figs/drawing_connection_parallel.SLDPRT
2210.0 x 2122.6 x 1460.3 mm

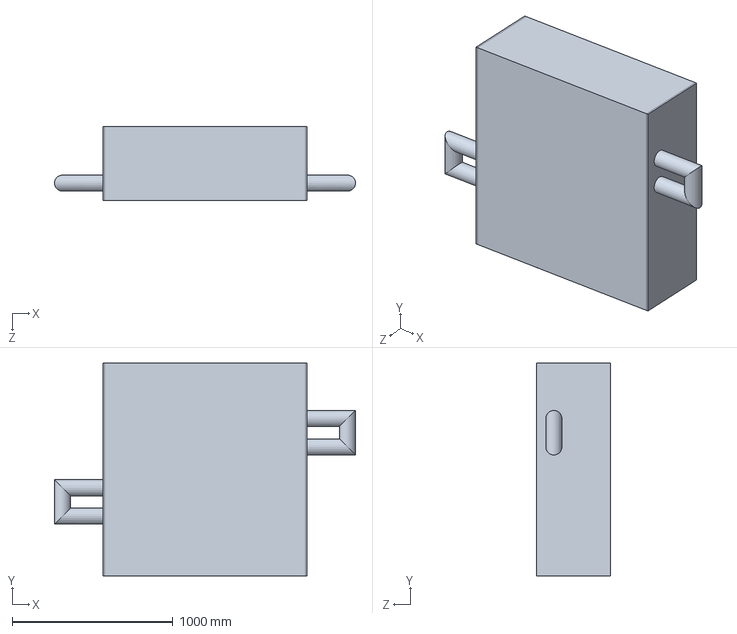
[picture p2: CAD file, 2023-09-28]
figs/drawing_connection.SLDPRT
1870.0 x 1322.6 x 460.3 mm

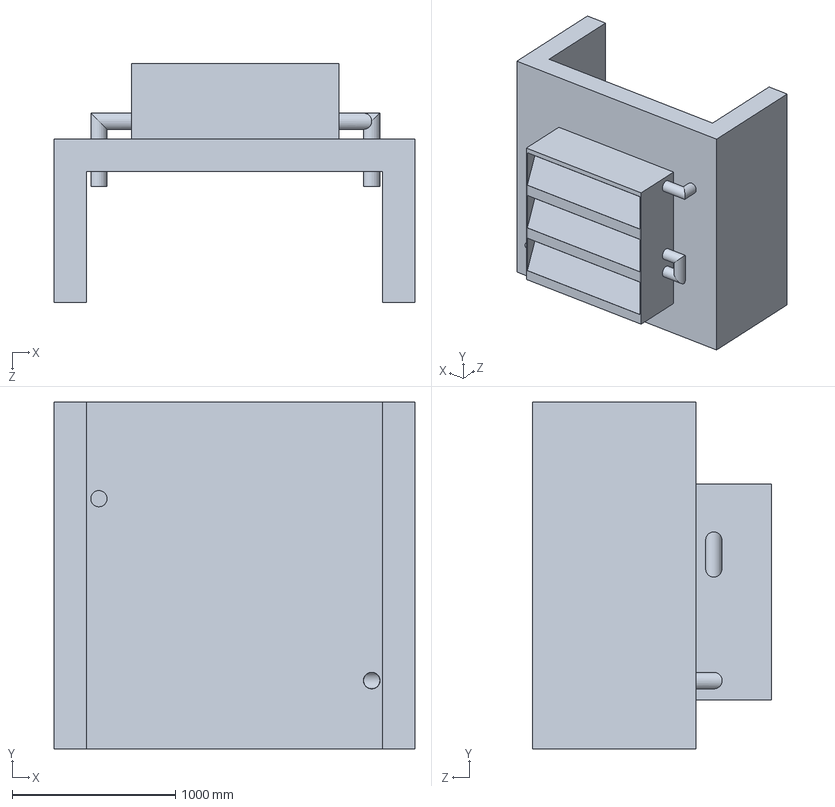
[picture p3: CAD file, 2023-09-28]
figs/drawing_connection_series.SLDPRT
2210.0 x 2122.6 x 1460.3 mm

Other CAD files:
figs/drawing_connection_combo1-23.SLDPRT
figs/design_suport.SLDPRT
figs/drawing_connection_combo12-3.SLDPRT

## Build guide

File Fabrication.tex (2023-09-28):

\chapter{Fabrication and Experiments in a prototype}
\label{Cap:Fabrication}
%

The results of the tests

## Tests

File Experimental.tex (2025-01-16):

\chapter{Experimental performance analysis}
\label{Cap:Exp}
%\vspace{-1.0cm}
%

This chapter aims to analyse the outdoor experimental performance of the solar air heater prototype fabricated using the concentrator designed in Chapter \ref{Cap:Opt}. This air heating system was fabricated and tested at Technological University Dublin, Ireland. The specific objectives are to:

\begin{itemize}
	\item Present the materials and components for fabrication;
	\item Describe the data collection procedure and equipment used;
	\item Evaluate the thermal performance of the system in an open loop configuration.
\end{itemize}

\section{Materials for the prototype}
	
\subsection{Absorber surface selection}

The function of the absorber surface in solar thermal systems is to retain thermal energy from incoming solar radiation. To meet this objective, carbon fibre weave fabric has been selected as the absorbing material (Figure \ref{CFphoto}). Although it is not conventionally employed in solar air heating systems (\cite{Shams2013}), its utilisation brings two advantages: i) it has natural perforations, and ii) it reduces the system's weight -- compared to an aluminium plate of the same dimensions, the carbon fibre surface is 40\% lighter.

\Figure[scale=0.3,placement=!ht,label={CFphoto},caption={Carbon fibre weave fabric (\cite{EasyComposites2017}).}]{figs/CFphoto.PNG}

\newpage
Carbon fibre weave's physical properties are presented in Table \ref{carbonfiber}. Absorptivity data were reported by \citet{Wu2012}, whereas thermal conductivity and specific heat were obtained from the material supplier Easy Composites (\cite{EasyComposites2017}). Despite being a modest thermal conductor, \citet{Gawlik2005} reported that this factor poorly influences the thermal efficiency of an air heating system with a perforated absorber.

\begin{table}[!ht]
	\caption{Carbon fibre weave properties.}
	\centering
	\begin{tabular}{p{5cm}p{4cm}}
		\hline \\[-12pt] 
		Property & Value \\ 
		\hline \\[-12pt] 
		Thickness & 0.30 mm \\ [3pt]
		Density & 1790 kg/m$^3$ \\ [3pt]
		Thermal Conductivity & 10.42 W/(m K) \\ [3pt]
		Specific Heat & 795 J/(kg K) \\ [3pt]
		Absorptivity & 0.85 \\ [1pt]
		\hline 
	\end{tabular} 
	\label{carbonfiber}
\end{table}

The carbon fibre weave fabric is made of multi-filament yarns, and the type of weave is considered according to the application (\cite{Tourlonias2016}). The area between the woven yarns are the perforations through which the flowing air passes. This porosity was calculated from data from morphology images (Figure \ref{CFmag}) by \citet{Shams2013}. The average perforation area and porosity values are 0.147 mm$^2$ and 4.2\%, respectively, and will be input as parameters in the thermal modelling depicted in \mbox{Chapter \ref{Cap:Thermal}}. The cost of this carbon fibre weave fabric was 24 \euro/${\rm m^2}$.

\Figure[scale=0.65,placement=!ht,label={CFmag},caption={Morphology image of carbon fibre sample taken at magnification of 15x.}]{figs/CFmag}

Epoxy laminating resin was applied to the corners of the surface to assemble the carbon fibre fabric onto the prototype. This was done to prevent splitting in the weave and ensure the surface remained stretched. The corners were then secured to a thin wooden frame with specific absorber dimensions (0.145 m x 1.25 m).

\subsection{Glazing cover selection}

A glazing material that enhances light transmission and avoids optical losses is needed. For the task, the selected glazing material for this system is a 4-mm thick tempered clear glass slab. This tempered property makes the glass safer and more durable than ordinary glass. It withstands 5 times more impact before shattering. If shattered, the fragments pose a reduced danger to the user, making it an attractive product for use in both commercial and domestic applications (\cite{FirstGlass2016}). The glass properties, such as absorptivity and transmittance, are shown in Table \ref{glass_tempered}. From the collector's design, the glazing dimensions are \mbox{0.27 m x 1.25 m}. The cost of the glass was 70 \euro/${\rm m^2}$.

\begin{table}[!ht]
	\caption{Glazing cover properties.}
	\centering
	\begin{tabular}{p{5cm}p{4cm}}
		\hline \\[-12pt] 
		Property & Value \\ 
		\hline \\[-12pt] 
		Thickness & 4 mm \\ [3pt]
		Density & 2500 kg/m$^3$ \\ [3pt]
		Absorptivity\footnotemark[1] & 0.02 \\ [3pt]
		Transmittance\footnotemark[1] & 0.90 \\ [3pt]
		Specific Heat & 880 J/(kg.K)  \\ [1pt]
		\hline 
	\end{tabular} 
	\label{glass_tempered}
\end{table}

\footnotetext[1]{Values at near normal incident light}

\subsection{Reflector surface selection}

The reflective material employed is \textit{MiroSun} from the German company Alanod, the only product used for solar applications. This reflective aluminium sheet is manufactured using a continuous physical vapour deposition (PVD) process applied for a super reflective layer to coil anodised material. Afterwards, the surface is protected by a nano-composite in a coil-coating process. Table \ref{reflector_M} shows the optical and physical properties of this material. From the concentrator's design, the total area of the reflector sheet used was 1.25 m x 1.20 m. The cost of the Alanod reflector was 50 \euro/${\rm m^2}$.

\begin{table}[!ht]
	\caption{\textit{MiroSun} reflector properties (\cite{Alanod2016}).}
	\centering
	\begin{tabular}{p{5cm}p{4cm}}
		\hline \\[-12pt] 
		Property & Value \\ 
		\hline \\[-12pt] 
		%Front Side Layer & PVD improved \\ [3pt]
		%Reverse Side Layer & Anodised \\ [3pt]
		Thickness & 0.5 mm \\ [3pt]
		Density & 2700 kg/m$^3$ \\ [3pt]
		%Max. Width & 1.25 m \\ [3pt]
		Total Reflectivity & 0.95 \\ [1pt]
		\hline 
	\end{tabular} 
	\label{reflector_M}
\end{table}

\subsection{Prototype's structure}

The materials used to fabricate the prototype's structure are listed as follows:

\begin{itemize}
	\item 0.7 m$^2$ of a 2-mm thick aluminium sheet to form the ends;
	\item 8 aluminium bars of 1.25 m in length to support and keep the reflectors in the desired position;
	\item 0.45 m$^2$ of 1-cm thick timber to form a cavity above the absorber surface in order to reduce heat losses;
	\item two 2.5-in diameter aluminium pipes of 10 cm in length for the airflow inlet and outlet;
	\item 1.8 m$^2$ of a 0.6-mm thick aluminium sheet to box the whole structure.
	
\end{itemize}

Figure \ref{Ass11} shows photographs of the assembled structure. The space between the reflectors and the outer aluminium sheet was filled with fibre glass wool to provide thermal insulation. The structure was wrapped with polyurethane foam board and sealed with waterproof tape.

\begin{figure}[ht!]
	\begin{minipage}{0.49\columnwidth}
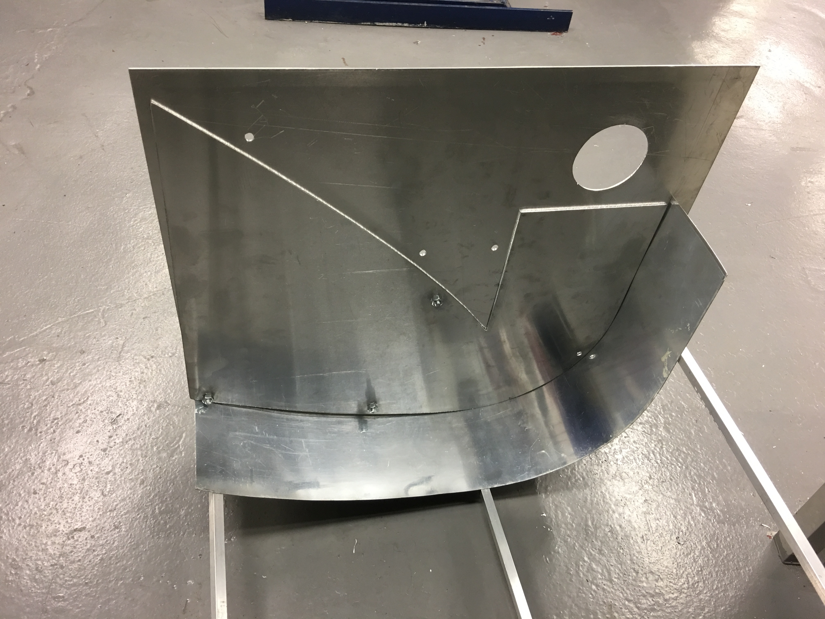
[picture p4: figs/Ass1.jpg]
		
		\subcaption{One end assembled.}
		
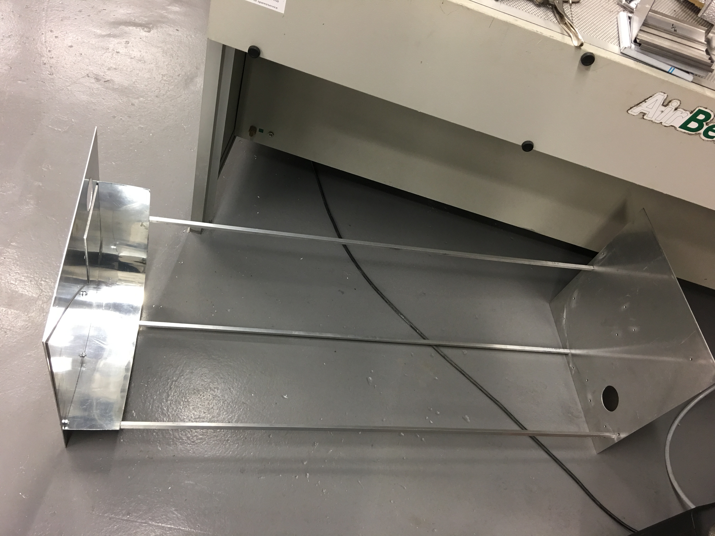
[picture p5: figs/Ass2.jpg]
		
		\subcaption{Two ends and aluminium bars assembled.}
	\end{minipage}
	\begin{minipage}{0.49\columnwidth}
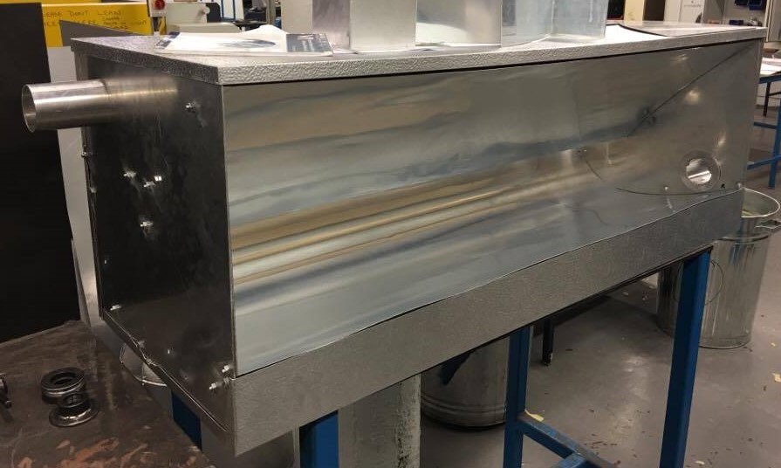
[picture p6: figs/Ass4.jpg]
		
		\subcaption{Closed structure.}
		
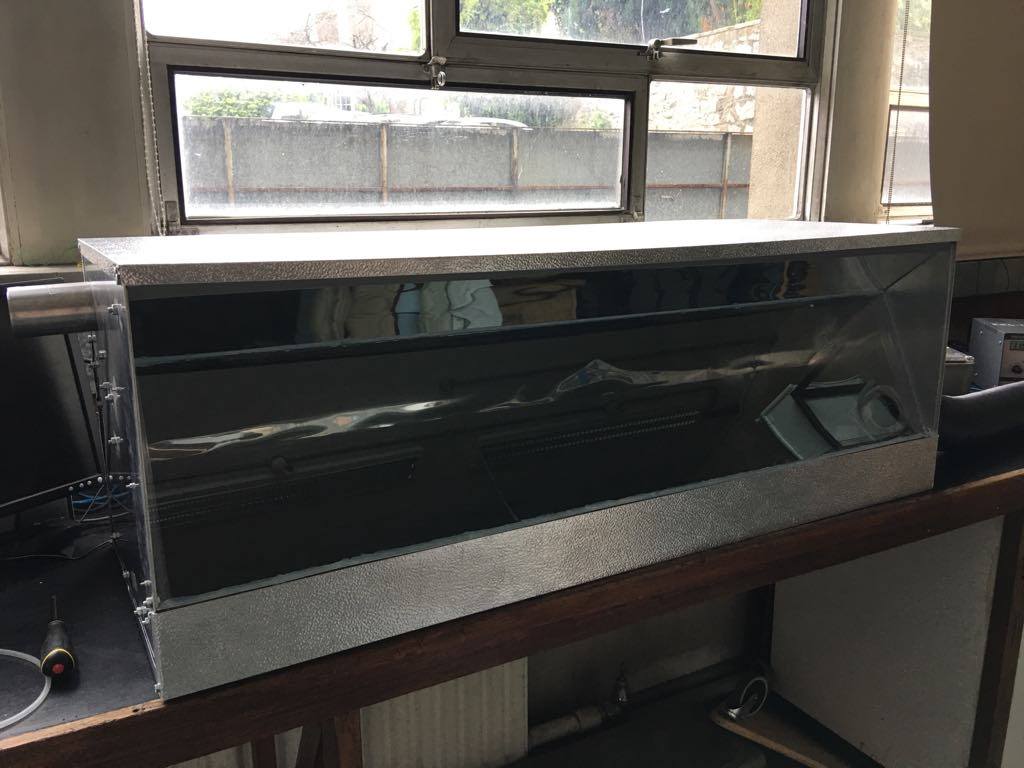
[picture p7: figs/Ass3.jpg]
		
		\subcaption{Closed structure with the glass.}
		
	\end{minipage}
	\caption{Parts of the prototype's structure and assembled}
	\label{Ass11}
\end{figure}

%\Figure[scale=0.45,placement=!ht,label={Structure1},caption={Aluminium structure of the solar air heater.}]{figs/Structure1.png}

\section{Instrumentation of the experimental unit}

Temperatures were measured at the inlet and outlet of air, absorber and glazing surfaces using type T (Cu-CuNi) PTFE insulated twist fine wire thermocouple sensors with an accuracy of $\pm$0.5 $^{\rm{o}}$C. Figures \ref{TC_abs} and \ref{TC_glaz} indicate the position of each thermocouple on the absorber and glazing surfaces, respectively. 18 thermocouples were used in total. As a matter of orientation, in both figures, the side where the thermocouple 1 is placed is the closest to the outlet.

\Figure[scale=0.50,placement=!ht,label={TC_abs},caption={Positions of the 12 thermocouples numbered from 1 to 12 placed on the absorber surface (dimensions in mm).}]{figs/absorber_thermocouple.PNG}

\Figure[scale=0.40,placement=!ht,label={TC_glaz},caption={Position of the three thermocouples numbered from 1 to 3 placed on the glazing surface (dimensions in mm).}]{figs/glass_thermocouple.PNG}

These temperature measurements were recorded at 1-minute intervals with a DL2e data logger connected directly to a computer, where the temperature data were downloaded via a USB port (\cite{Devices2018}). All thermocouples were labelled, inserted in a plug and connected to the data logger.

\newpage
The airflow was provided by a 12-W fan, where the rate was varied by a voltage adaptor with five different voltage inputs. The air velocity at the air outlet ($\rm{v_{in}}$, in m/s) was measured using a Testo 425 hot wire anemometer. These velocity levels were converted to airflow values using Eq. (\ref{Gpitot}).

%\begin{equation}
%\mathrm{{v_{out}} = \sqrt {\frac{{2{\mathrm{P_{out}}}}}{{{\mathrm{d_{air}}}}}}}
%\label{Vpitot}
%\end{equation}

\vspace{-0.75cm}
\begin{equation}
\mathrm{{G_{air}} = \frac{{{v_{in}}{A_{out}}{d_{air}}}}{{{A_{abs}}}}}
\label{Gpitot}
\end{equation}

\noindent where $\rm{A_{out}}$ is the cross-section area of the outlet pipe (m$^2$), $\rm{d_{air}}$ is the air density (kg/m$^3$) and  $\rm{G_{air}}$ is the mass airflow rate per absorber area (kg/(s.m$^{{\rm{2}}}$)).

The measured variables are subjected to systematic uncertainties due to instrumentation errors. It is thus necessary to calculate the standard uncertainty of each variable measured for the experimental work. Those measurements are temperature, air velocity and solar radiation. The accuracy of each instrument, taken from the manufacturer data is shown in Table \ref{uncertainty}.   

\begin{table}[!ht]
	\caption{Measurements and standard uncertainty.}
	\centering
	\begin{tabular}{p{3.0cm}p{3.5cm}p{3.5cm}}
		\hline \\[-10pt] 
		\rule[-1ex]{0pt}{2.5ex} Measurement & Accuracy & Uncertainty \\ [3pt]
		\hline \\[-10pt]
		\rule[-1ex]{0pt}{2.5ex} Temperature & ${\rm \pm0.55 ^{\rm o}C \pm0.3 ^{\rm o}C}$ & 0.36 $^{\rm o}$C \\ [5pt]
		\rule[-1ex]{0pt}{2.5ex} Air velocity &  $\pm$(0.03 + 5\% of ${\rm v_{in})}$ & 0.0173 + 0.0289${\rm v_{in}}$ \\ [5pt] 
		%\rule[-1ex]{0pt}{2.5ex}  & 0.070 & 650 \\ [5pt]
		%\rule[-1ex]{0pt}{2.5ex} 8.70 & 0.090 & 820 \\ [5pt]
		\rule[-1ex]{0pt}{2.5ex} Solar radiation & -- & 1\% of ${\rm I_{\!_T}}$ \\ [2pt]
		\hline 
	\end{tabular}
	\label{uncertainty}
	
\end{table}

\newpage
Table \ref{GxV} shows the air velocity and airflow rate values as a function of the voltage input input ($\rm{V_a}$) and a category corresponding to each level. Systematic uncertainties were also calculated for the airflow rate (${\rm u_g}$).

\begin{table}[!ht]
	\caption{Mass and volumetric flow rates calculated at each voltage input.}
	\centering
	\begin{tabular}{p{2.1cm}p{1.8cm}p{2.4cm}p{2.2cm}p{1.8cm}}
		\hline \\[-10pt] 
		\rule[-1ex]{0pt}{2.5ex} Voltage (V) & ${\rm v_{in}}$ (m/s) & $\rm{G_{air}}$ (kg/m$^2$.s) & ${\rm u_{g}}$ (kg/m$^2$.s)  & Code \\ [3pt]
		\hline \\[-10pt]
		\rule[-1ex]{0pt}{2.5ex} 4.92 & 1.83 & 0.038 & 0.0021 & Low\\ [5pt]
		\rule[-1ex]{0pt}{2.5ex} 5.82 & 2.59 & 0.054 & 0.0030 & Low-med \\ [5pt] 
		\rule[-1ex]{0pt}{2.5ex} 7.20 & 3.43 & 0.071 & 0.0039 & Medium \\ [5pt]
		\rule[-1ex]{0pt}{2.5ex} 8.70 & 4.30 & 0.089 & 0.0048 & Med-high  \\ [5pt]
		\rule[-1ex]{0pt}{2.5ex} 11.30 & 5.50 & 0.114 & 0.0060 & High \\ [2pt]
		\hline 
	\end{tabular} 
	\label{GxV}
\end{table}

%Hence, a 2$^{\rm{nd}}$ degree polynomial was fit from the previous data, as shown in \mbox{Eq. (\ref{Gfit}):} 

%\begin{equation}
%\mathrm{{G_{air}} =  - 6.3 \cdot {10^{ - 4}}V_a^2 + 0.022V_a - 0.054}
%\label{Gfit}
%\end{equation}

%The pressure drop across the prototype was calculated at each airflow level and are presented in Figure \ref{dP-Gair}.

%\Figure[scale=0.50,placement=!ht,label={dP-Gair},caption={Pressure drop for different mass airflow rates}]{figs/dP-Gair.eps}

An open-loop experimental system diagram is shown in Figure \ref{scheme_p}. A flexible duct was connected to the prototype's inlet. The fan flowed air through the duct to the collector. The power supply unit provided voltage to the fan and energy to the data logger.

\Figure[scale=0.90,placement=!ht,label={scheme_p},caption={Schematic diagram of the experimental unit.}]{figs/scheme_prototype.png}

Figure \ref{unit1} presents the prototype's front view. It was fixed to the ground to prevent it from moving due to severe wind conditions. The fan was enclosed and protected from the environment during the experiments, and the data logger was placed behind the prototype.

\Figure[scale=0.48,placement=!ht,label={unit1},caption={Open-loop outdoor prototype.}]{figs/unit3.png}

\section{Experimental results from the air heating prototype}

This section presents the experimental results from tests conducted at the five airflow rates and those without flow. The thermal performance of the prototype focused on evaluating the useful energy rate (or energy delivered), collector thermal efficiency and outlet air temperature. The useful heat rate transferred to the airflow is estimated by Eq. (\ref{usefulenergy}) (\cite{Kalogirou2004}) using temperature measurements from the inlet and outlet:

\vspace{-0.75cm}
\begin{equation}
\mathrm{{Q_u} = {G_{air}}{A_{abs}}{C_{p,air}}({T_{out}} - {T_{in}})}
\label{usefulenergy}
\end{equation}

The thermal efficiency, which is the ratio of useful heat rate to the incoming total solar radiation on the aperture, is calculated by Eq. (\ref{ThermalEf0}). The solar radiation data used in the calculations were downloaded from the Met Eireann website (\cite{MetEireann2018}). Such data were measured by a solar pyranometer placed at the horizontal.

\subsection{Experimental results at transient state}

Experimental results of measured temperatures and solar radiation were used to calculate energies and thermal efficiency hourly. One day of each level of airflow rate was taken for data treatment and discussion, from 9:00 to 17:00 in 2018. 

\subsubsection{Experimental results at zero airflow}

The equilibrium temperature that the absorber approaches when no energy is removed from the collector is known as the stagnation temperature (\cite{Rabl1985}). To verify this condition, the system's inlet and outlet were closed, and two tests were conducted on clear sky days, specifically on 2$^{\rm{nd}}$ and 3$^{\rm{rd}}$ July, as shown in Figure \ref{zero12}. The temperature profile of the absorber represents the average measurements from all 12 thermocouples placed on its surface. During both tests, peaks of maximum stagnation absorber temperatures reached 77 $^{\rm{o}}$C with an average $\rm{I_{\!_T}}$ of 830 W/m$^{\rm{2}}$ and $\rm{T_{amb}}$ of 22 $^{\rm{o}}$C occuring around 14:00 on both days.

\Figure[scale=0.70,placement=!ht,label={zero12},caption={Experimental results from 2$^{\rm{nd}}$ and 3$^{\rm{rd}}$ July at zero airflow.}]{figs/zero12.eps}

Figure \ref{thermocouples} shows the measured temperatures for each thermocouple positioned on the absorber surface in order to investigate the stagnation point. The temperatures at the left end (T10/T11/T12) are slightly higher than those at the right (T1/T2/T3). This difference can be attributed to the fact that at 14:00 on 2$^{\rm nd}$ July, the Sun's altitude and azimuth angles are 59$^{\rm o}$ and 14\textdegree. Consequently, a concentration of energy may be occurring on the left side, which explains the temperature variation. Another observation is that the energy flux was well distributed along the area, as most temperatures are near the average value.

\Figure[scale=0.40,placement=!ht,label={thermocouples},caption={Temperatures measured by the thermocouples on the absorber surface.}]{figs/thermocouples.png}

This result can be compared to the energy distribution obtained by the ray tracing algorithm used in Chapter 3 and shown in Figure \ref{case_ch4}. The analysis indicates that the left end of the absorber surface received significantly more energy compared to the right end, which is clearly reflected in the corresponding measured temperatures. In particular, the higher temperatures at the left end suggest that it is more effectively absorbing energy. Conversely, although the right end does not receive direct radiation, its temperatures are still relatively close to the average. This suggests that some level of energy redistribution or thermal conduction may be occurring. In summary, this analysis provides a means to validate the previously developed optical modelling.

\Figure[scale=0.40,placement=!ht,label={case_ch4},caption={Energy distribution on the absorber surface obtained via ray tracing, where the Sun's altitude and azimuth angles are 59$^{\rm o}$ and 14\textdegree.}]{figs/case_ch4.eps}

\newpage
\subsubsection{Experimental results with airflow}

The findings of a low airflow rate (0.038 kg/m$^2$.s) experiment are presented in Figure \ref{004}. It was conducted on 9$^{\rm{th}}$ June under clear sky conditions with the highest solar radiation values at the solar noon hour (13:00 -- 14:00), where its peak is 860 W/m$^2$. During this hour, the average outlet airflow temperature $\rm{T_{out}}$, ambient temperature $\rm{T_{amb}}$, and thermal efficiency $\eta_{\rm{th}}$ were observed to have average values of 51 $^{\rm{o}}$C, 23 $^{\rm{o}}$C, and 0.53, respectively. At around the peak of solar radiation, the maximum $\rm{T_{out}}$ was found to be 51~$^{\rm{o}}$C, resulting in an airflow temperature rise of 28 $^{\rm{o}}$C and a corresponding $\eta_{\rm{th}}$ of 0.54. The total incident solar radiation received during the test was estimated to be 20.46 MJ/m$^2$, of which a total useful energy collected $\rm{Q_{u}}$ of 7.64 MJ/m$^2$ was calculated, resulting in a daily thermal efficiency of 0.35.

\begin{figure}[!ht]
	\centering
	\begin{minipage}{0.49\textwidth}
		\centering
		 % first figure itself
		\subcaption{Temperature results and solar data.}
	\end{minipage}\hfill
	\begin{minipage}{0.49\textwidth}
		\centering
		 % second figure itself
		\subcaption{Hourly performance and solar data.}
	\end{minipage}

	\caption{Experimental results from 9$^{\rm{th}}$ June at 0.038 kg/(s m$^2$).}
	\label{004}
\end{figure}

The results of an experiment conducted at a low-medium airflow rate (0.055 kg/m$^2$.s) under relatively clear sky conditions are depicted in Figure \ref{0055}. During the solar noon hour (13:00 -- 14:00), the airflow collected 1.7 MJ/m$^2$ of energy at an average outlet temperature of 43 $^{\rm{o}}$C and thermal efficiency of 55\%. The highest outlet temperature ($\rm{T_{out}}$) was recorded as 42 $^{\rm{o}}$C when the ambient temperature ($\rm{T_{amb}}$) was 20 $^{\rm{o}}$C, resulting in a maximum temperature rise of 22 $^{\rm{o}}$C. The total solar energy available was 21.29 MJ/m$^2$, while the total useful energy collected was 9.56 MJ/m$^2$. The thermal efficiency obtained for this day was 43\%.

%The highest outlet temperature ($\rm{T_{out}}$) was recorded as 43 $^{\rm{o}}$C when the ambient temperature ($\rm{T_{amb}}$) was 21 $^{\rm{o}}$C. The maximum temperature rise of the airflow was observed to be 22 $^{\rm{o}}$C, and the corresponding thermal efficiency ($\eta_{\rm{th}}$) during this period was estimated at 55\%. The total solar energy available was 21.29 MJ/m$^2$, while the total useful energy collected was 9.56 MJ/m$^2$. The thermal efficiency obtained for this day was 43\%. During the solar noon hour (13:00 -- 14:00), the airflow collected 1.7 MJ/m$^2$ of energy at an average outlet temperature of 43 $^{\rm{o}}$C.

%The experimental results of this test operating at low-med airflow (0.055 kg/m$^2$.s) are shown in Figure \ref{0055} under relatively clear sky condition. The highest $\rm{T_{out}}$ measured was 43 $^{\rm{o}}$C  when $\rm{T_{in}}$ = 23 $^{\rm{o}}$C and $\rm{T_{amb}}$ = 21 $^{\rm{o}}$C. The maximum airflow temperature rise was 20 $^{\rm{o}}$C observed between 13:00 and 14:00. The thermal efficiency ($\eta_{\rm{th}}$) on this same region was 55\%. The total solar energy available on 22$^{\rm{nd}}$ June was 21.29 MJ/m$^2$; the total useful energy collected was 9.56 MJ/m$^2$; and the thermal efficiency for this day obtained was 43\%. In the hour of solar noon (13h -- 14h), the airflow collected 1.7 MJ/m$^2$ of energy at an average $\rm{T_{out}}$ of 43 $^{\rm{o}}$C.

\begin{figure}[!ht]
	\centering
	\begin{minipage}{0.49\textwidth}
		\centering
		 % first figure itself
		\subcaption{Temperature results and solar data.}
	\end{minipage}\hfill
	\begin{minipage}{0.49\textwidth}
		\centering
		 % second figure itself
		\subcaption{Hourly performance and solar data.}
	\end{minipage}
	
	\caption{Experimental results from 22$^{\rm{nd}}$ June at 0.054 kg/(s m$^2$).}
	\label{0055}
\end{figure}

The experimental results of the test operating at medium airflow (0.07 kg/m$^2$.s) are shown in Figure \ref{007} on 29$^{\rm{th}}$ May, in relatively clear sky conditions. The highest $\rm{T_{out}}$ was measured to be 41 $^{\rm{o}}$C  when $\rm{T_{amb}}$ was 21 $^{\rm{o}}$C. The maximum airflow temperature rise was 20 $^{\rm{o}}$C observed between 13:00 and 14:00. The thermal efficiency ($\eta_{\rm{th}}$) in this region was 58\%. The total incident solar energy available on this day was 21.4 MJ/m$^2$; the total useful energy collected was 10.03 MJ/m$^2$, and the average thermal efficiency obtained was 46\%. In the hour of highest solar radiation, the airflow collected 1.7 MJ/m$^2$ of energy at an average $\rm{T_{out}}$ of 40 $^{\rm{o}}$C.

\begin{figure}[!ht]
	\centering
	\begin{minipage}{0.49\textwidth}
		\centering
		 % first figure itself
		\subcaption{Temperature results and solar data.}
	\end{minipage}\hfill
	\begin{minipage}{0.49\textwidth}
		\centering
		 % second figure itself
		\subcaption{Hourly performance and solar data.}
	\end{minipage}
	
	\caption{Experimental results from 29$^{\rm{th}}$ May at 0.071 kg/(s m$^2$).}
	\label{007}
\end{figure}

\newpage
The results of the test at med-high airflow (0.089 kg/m$^2$.s) are shown in Figure \ref{009} on 31$^{\rm{st}}$ May. Although the solar data is very transient on this day, $\rm{T_{out}}$ kept constant around 39 $^{\rm{o}}$C  when $\rm{T_{amb}}$ was 23 $^{\rm{o}}$C at solar noon hour. The maximum airflow temperature rise was 16 $^{\rm{o}}$C at the same hour. The thermal efficiency in this region was 59\%. The total solar radiation available was 15.6 MJ/m$^2$, $\rm{Q_{u}}$ was 7.18 MJ/m$^2$, and the average thermal efficiency obtained was 46\%. In the hour with highest solar radiation, the airflow collected 1.6 MJ/m$^2$ of energy at an average $\rm{T_{out}}$ of 39 $^{\rm{o}}$C.

\begin{figure}[!ht]
	\centering
	\begin{minipage}{0.49\textwidth}
		\centering
		 % first figure itself
		\subcaption{Temperature results and solar data.}
	\end{minipage}\hfill
	\begin{minipage}{0.49\textwidth}
		\centering
		 % second figure itself
		\subcaption{Hourly performance and solar data.}
	\end{minipage}
	
	\caption{Experimental results from 31$^{\rm{st}}$ May at 0.089 kg/(s m$^2$).}
	\label{009}
\end{figure}
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

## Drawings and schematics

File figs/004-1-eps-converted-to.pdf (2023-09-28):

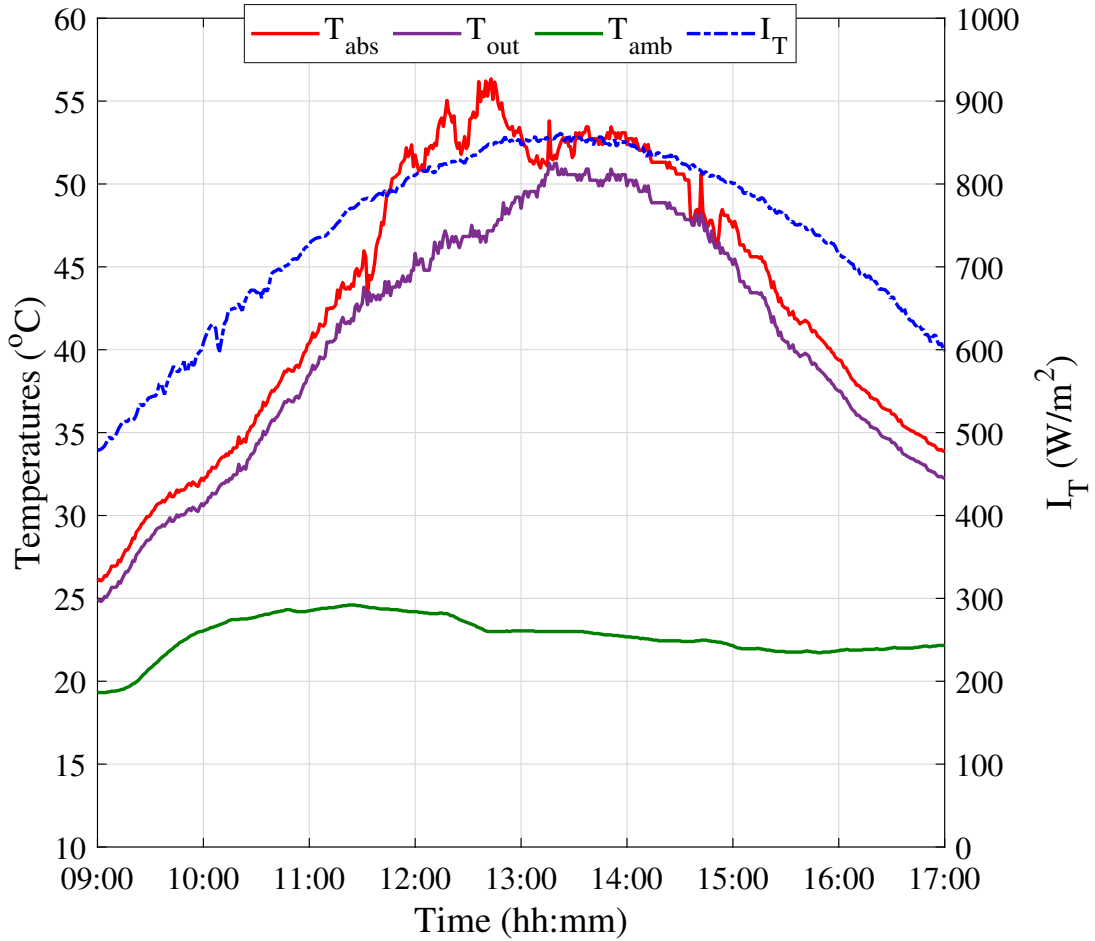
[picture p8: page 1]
Temperatures (; abs; out; amb

Time (hh:mm)

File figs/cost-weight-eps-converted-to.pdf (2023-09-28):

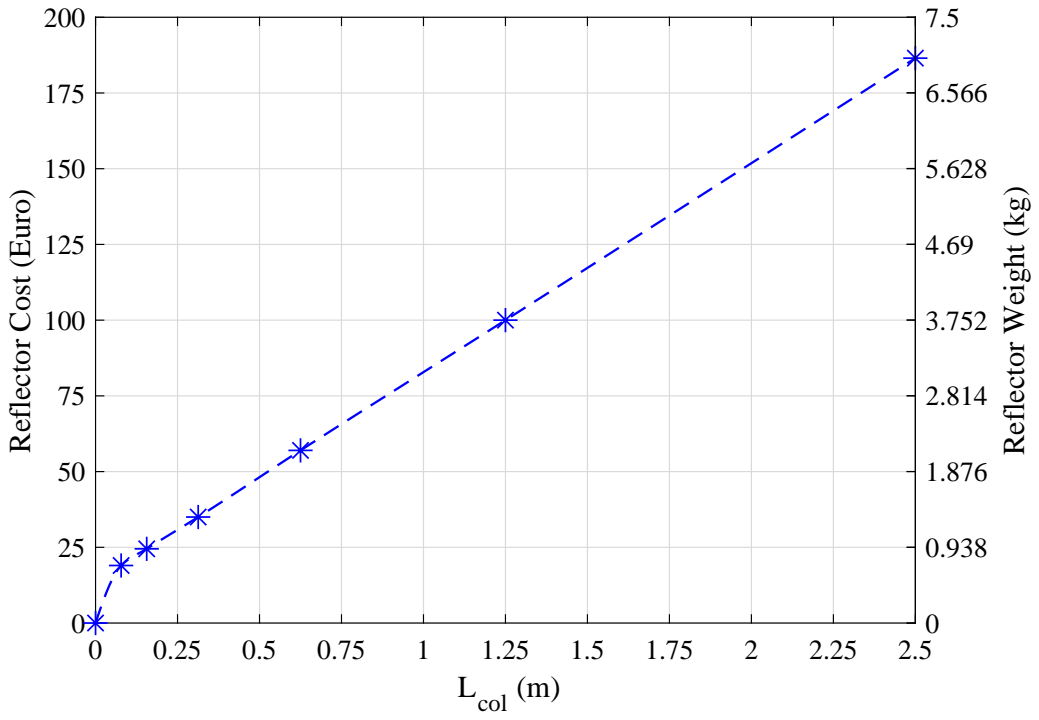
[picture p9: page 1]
Lcol (m)

Reflector Cost (Euro)

Reflector Weight (kg)

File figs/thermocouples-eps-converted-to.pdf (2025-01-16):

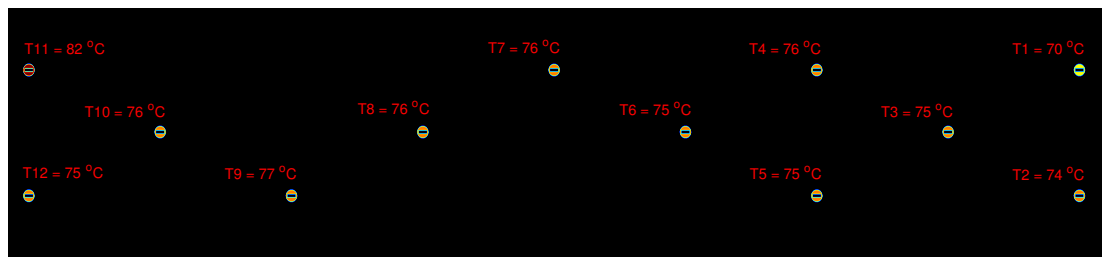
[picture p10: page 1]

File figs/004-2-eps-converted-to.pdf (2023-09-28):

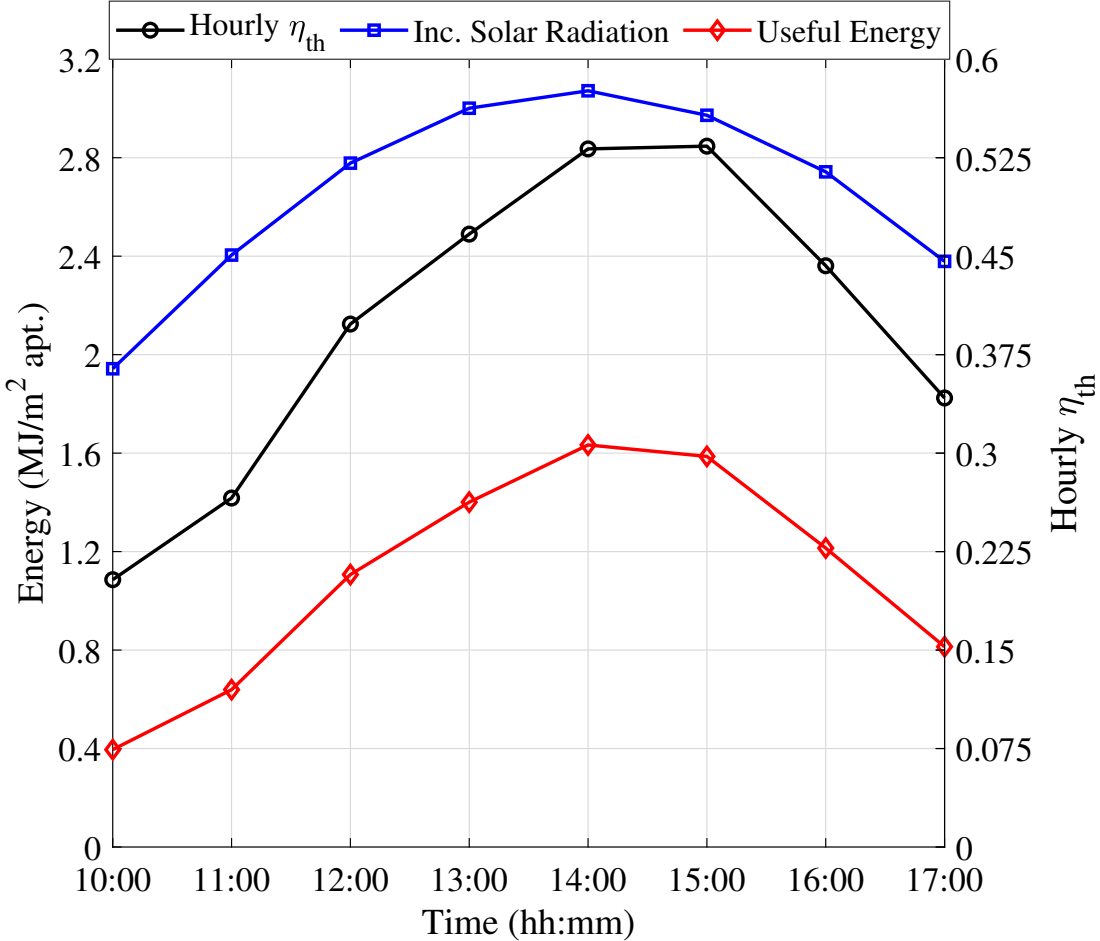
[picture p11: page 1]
Energy (MJ/m; 2 apt.); Hourly th; Inc. Solar Radiation; Useful Energy

Time (hh:mm)
